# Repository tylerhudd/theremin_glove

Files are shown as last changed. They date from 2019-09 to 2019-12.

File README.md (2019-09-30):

# Theremin Glove
The Theremin Glove is a theremin inspired electronic instrument. Like the theremin, it is played with hand movements and gestures in the air. In electronics terms, it is a digitally controlled analog synthesizer and a wireless glove controller.
 
This project was started for the Johns Hopkins Whiting School of Engineering *Embedded Systems Lab* course in September 2019 and the working prototype should be demonstrated in December 2019. This course is an Electrical and Computer Engineerng graduate level capstone class that emulates the design process from requirement definitions to project demonstration.

I came up with the concept for this project as a way to combine areas of my engineering interests, which include:
* Analog circuit design
* Digital circuit design
* Firmware design (in this case, it's C programming for the ATMega328P)
* PCB design

## Features
* Pitch control - raising and lowering hand raises and lowers the frequency generated by the analog synthesizer
* Definable pitch range - the pitch range is set by first defining where the lowest note exists (i.e. place hand at the bottom of range) and press a button to start range recording. Then raise hand to where the highest note is and press a button to save. This is required because hand placement will be detected by an accelerometer which doesn't measure absolute height.
* Tone control - tilting hand in and out sweeps the resonant frequencies of the analog filters in the synthesizer
* Volume control - opening and closing hand raises and lowers the volume

## System
### Glove
* XBee3 wireless RF transceiver - transmits sensor data to digital analog synthesizer controller
* ATMega328P microcontroller - reads the sensor data and pushes to the XBee3 over SPI
* I2C interface to 6DoF sensor
* ADC interface to bend sensor
* USB-UART interface to ATMega328P and XBee3 for debug
* AVR SPI ISP header for ATMega328P programming
* Battery powered
* USB re-chargeable

### Digital Analog Synthesizer Controller
* XBee3 wireless RF transceiver - receives sensor data from glove
* ATMega328P microcontroller - interprets sensor data and calculates controls to analog synthesizer
* I2C interface to 4-channel DAC and IO expander
* USB-UART interface to ATMega328P and XBee3 for debug
* AVR SPI ISP header for ATMega328P programming

### Analog Synthesizer
* 4-channel DAC - provides control voltages to analog circuis
* I2C IO expander - provides a greater number of control signals
* VCO - generates square, triangle, and sine waveforms
* VCF - variable low pass, band pass, and high pass filters
* VCA - variable volume amplifier
* Analog muxes to select waveforms and filtering
* Audio output

### Power Board
* Input 12VAC (2A max)
* Ouput :
 * +3.3V DC (1.5A max) for digital circuits
 * +/-12V DC (1.5A max each) for analog circuits

### Block Diagram
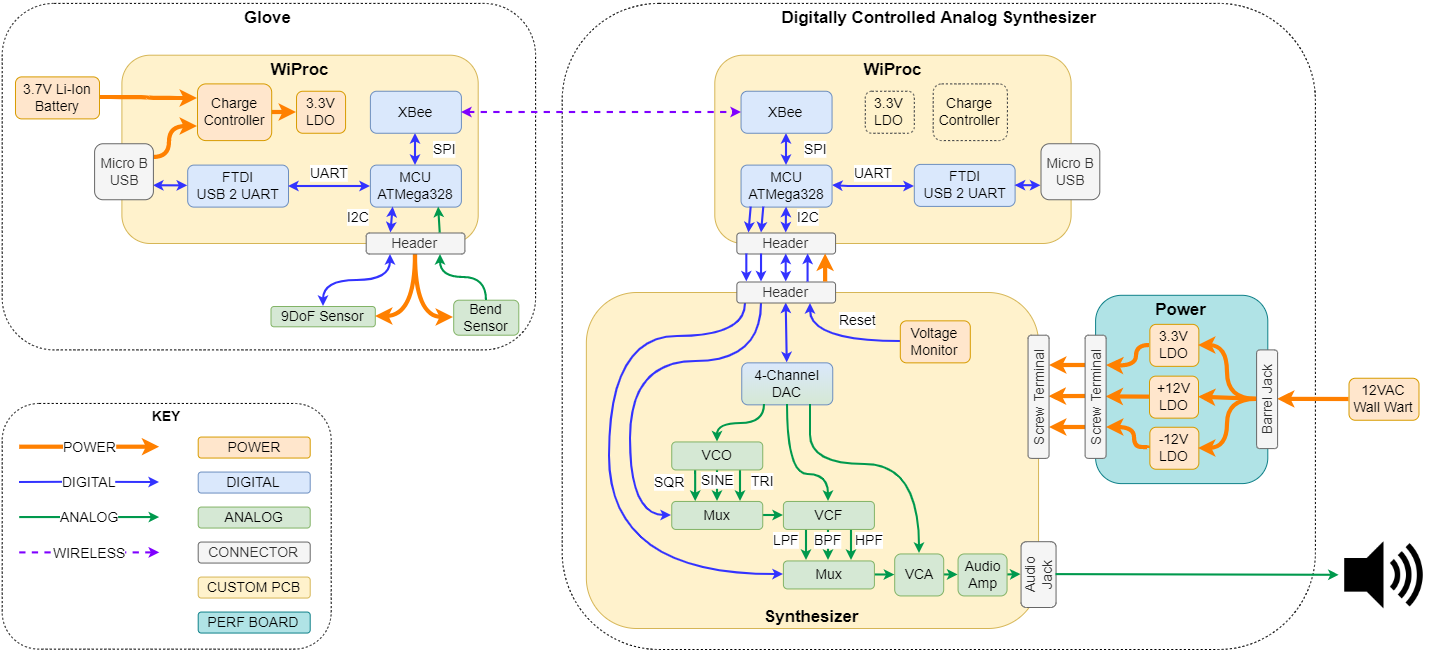
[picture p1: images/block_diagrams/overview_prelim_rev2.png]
block diagram


## Tools Used
* Atmel Studio - for ATMega328P C firmware development and programming
* KiCAD - for schematic capture and PCB design
* LTSpice - for analog and power simulations
* PuTTY - for serial console
* Github - for configuration management and project documentation

## Resources
* http://musicfromouterspace.com/
* https://oshpark.com/

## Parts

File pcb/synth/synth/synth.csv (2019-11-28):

Source: | C:\school\Johns_Hopkins\07_EmbeddedSystems\git\pcb\synth\synth\synth.sch
Date: | 11/10/2019 12:40:14 PM
Tool: | Eeschema (5.1.4)-1
Generator: | C:\Program Files\KiCad\bin\scripting\plugins/bom_csv_grouped_by_value.py
Component Count: | 161
Individual Components:
Item | Qty | Reference(s) | Value | LibPart | Footprint | Datasheet
 |  | BPF1 | TestPoint | Connector:TestPoint | TestPoint:TestPoint_Pad_1.0x1.0mm | ~
 |  | C1 | 680p | Device:C | Capacitor_SMD:C_0603_1608Metric_Pad1.05x0.95mm_HandSolder | ~
 |  | C2 | 680p | Device:C | Capacitor_SMD:C_0603_1608Metric_Pad1.05x0.95mm_HandSolder | ~
 |  | C3 | 680p | Device:C | Capacitor_SMD:C_0603_1608Metric_Pad1.05x0.95mm_HandSolder | ~
 |  | C4 | 1u | Device:C | Capacitor_SMD:C_0603_1608Metric_Pad1.05x0.95mm_HandSolder | ~
 |  | C5 | 1u | Device:C | Capacitor_SMD:C_0603_1608Metric_Pad1.05x0.95mm_HandSolder | ~
 |  | C6 | 0.47u | Device:C | Capacitor_SMD:C_0603_1608Metric_Pad1.05x0.95mm_HandSolder | ~
 |  | C7 | 0.1u | Device:C | Capacitor_SMD:C_0603_1608Metric_Pad1.05x0.95mm_HandSolder | ~
 |  | C8 | 0.1u | Device:C | Capacitor_SMD:C_0603_1608Metric_Pad1.05x0.95mm_HandSolder | ~
 |  | C9 | 0.1u | Device:C | Capacitor_SMD:C_0603_1608Metric_Pad1.05x0.95mm_HandSolder | ~
 |  | C10 | 0.1u | Device:C | Capacitor_SMD:C_0603_1608Metric_Pad1.05x0.95mm_HandSolder | ~
 |  | C11 | 0.1u | Device:C | Capacitor_SMD:C_0603_1608Metric_Pad1.05x0.95mm_HandSolder | ~
 |  | C12 | 1u | Device:C | Capacitor_SMD:C_0603_1608Metric_Pad1.05x0.95mm_HandSolder | ~
 |  | C13 | 0.1u | Device:C | Capacitor_SMD:C_0603_1608Metric_Pad1.05x0.95mm_HandSolder | ~
 |  | C14 | 0.1u | Device:C | Capacitor_SMD:C_0603_1608Metric_Pad1.05x0.95mm_HandSolder | ~
 |  | C15 | 0.1u | Device:C | Capacitor_SMD:C_0603_1608Metric_Pad1.05x0.95mm_HandSolder | ~
 |  | C16 | 0.1u | Device:C | Capacitor_SMD:C_0603_1608Metric_Pad1.05x0.95mm_HandSolder | ~
 |  | C17 | 0.1u | Device:C | Capacitor_SMD:C_0603_1608Metric_Pad1.05x0.95mm_HandSolder | ~
 |  | C18 | 1u | Device:C | Capacitor_SMD:C_0603_1608Metric_Pad1.05x0.95mm_HandSolder | ~
 |  | C19 | 0.1u | Device:C | Capacitor_SMD:C_0603_1608Metric_Pad1.05x0.95mm_HandSolder | ~
 |  | C20 | 0.1u | Device:C | Capacitor_SMD:C_0603_1608Metric_Pad1.05x0.95mm_HandSolder | ~
 |  | C21 | 0.1u | Device:C | Capacitor_SMD:C_0603_1608Metric_Pad1.05x0.95mm_HandSolder | ~
 |  | C22 | 0.1u | Device:C | Capacitor_SMD:C_0603_1608Metric_Pad1.05x0.95mm_HandSolder | ~
 |  | C23 | 1uF | Device:C | Capacitor_SMD:C_0603_1608Metric_Pad1.05x0.95mm_HandSolder | ~
 |  | C24 | 1uF | Device:C | Capacitor_SMD:C_0603_1608Metric_Pad1.05x0.95mm_HandSolder | ~
 |  | C25 | 0.1u | Device:C | Capacitor_SMD:C_0603_1608Metric_Pad1.05x0.95mm_HandSolder | ~
 |  | C26 | 0.1u | Device:C | Capacitor_SMD:C_0603_1608Metric_Pad1.05x0.95mm_HandSolder | ~
 |  | C27 | 0.1u | Device:C | Capacitor_SMD:C_0603_1608Metric_Pad1.05x0.95mm_HandSolder | ~
 |  | C28 | 0.1u | Device:C | Capacitor_SMD:C_0603_1608Metric_Pad1.05x0.95mm_HandSolder | ~
 |  | C29 | 2200p | Device:C | Capacitor_SMD:C_0603_1608Metric_Pad1.05x0.95mm_HandSolder | ~
 |  | C30 | 2200p | Device:C | Capacitor_SMD:C_0603_1608Metric_Pad1.05x0.95mm_HandSolder | ~
 |  | C31 | 68p | Device:C | Capacitor_SMD:C_0603_1608Metric_Pad1.05x0.95mm_HandSolder | ~
 |  | C32 | 0.1u | Device:C | Capacitor_SMD:C_0603_1608Metric_Pad1.05x0.95mm_HandSolder | ~
 |  | C33 | 0.1u | Device:C | Capacitor_SMD:C_0603_1608Metric_Pad1.05x0.95mm_HandSolder | ~
 |  | C34 | 1u | Device:C | Capacitor_SMD:C_0603_1608Metric_Pad1.05x0.95mm_HandSolder | ~
 |  | C35 | 0.1u | Device:C | Capacitor_SMD:C_0603_1608Metric_Pad1.05x0.95mm_HandSolder | ~
 |  | C36 | 0.1u | Device:C | Capacitor_SMD:C_0603_1608Metric_Pad1.05x0.95mm_HandSolder | ~
 |  | C37 | 1u | Device:C | Capacitor_SMD:C_0603_1608Metric_Pad1.05x0.95mm_HandSolder | ~
 |  | C38 | 0.1u | Device:C | Capacitor_SMD:C_0603_1608Metric_Pad1.05x0.95mm_HandSolder | ~
 |  | C39 | 0.1u | Device:C | Capacitor_SMD:C_0603_1608Metric_Pad1.05x0.95mm_HandSolder | ~
 |  | C40 | 0.1u | Device:C | Capacitor_SMD:C_0603_1608Metric_Pad1.05x0.95mm_HandSolder | ~
 |  | C41 | 0.1u | Device:C | Capacitor_SMD:C_0603_1608Metric_Pad1.05x0.95mm_HandSolder | ~
 |  | C42 | 0.1u | Device:C | Capacitor_SMD:C_0603_1608Metric_Pad1.05x0.95mm_HandSolder | ~
 |  | C43 | 0.1u | Device:C | Capacitor_SMD:C_0603_1608Metric_Pad1.05x0.95mm_HandSolder | ~
 |  | C44 | 0.1u | Device:C | Capacitor_SMD:C_0603_1608Metric_Pad1.05x0.95mm_HandSolder | ~
 |  | C45 | 1u | Device:C | Capacitor_SMD:C_0603_1608Metric_Pad1.05x0.95mm_HandSolder | ~
 |  | C46 | 0.1u | Device:C | Capacitor_SMD:C_0603_1608Metric_Pad1.05x0.95mm_HandSolder | ~
 |  | C47 | 10u | Device:C | Capacitor_SMD:C_0603_1608Metric_Pad1.05x0.95mm_HandSolder | ~
 |  | C48 | 0.1u | Device:C | Capacitor_SMD:C_0603_1608Metric_Pad1.05x0.95mm_HandSolder | ~
 |  | C49 | 0.1u | Device:C | Capacitor_SMD:C_0603_1608Metric_Pad1.05x0.95mm_HandSolder | ~
 |  | C51 | 10u | Device:C | Capacitor_SMD:C_0603_1608Metric_Pad1.05x0.95mm_HandSolder | ~
 |  | C52 | 10u | Device:C | Capacitor_SMD:C_0603_1608Metric_Pad1.05x0.95mm_HandSolder | ~
 |  | C53 | 10u | Device:C | Capacitor_SMD:C_0603_1608Metric_Pad1.05x0.95mm_HandSolder | ~
 |  | HPF1 | TestPoint | Connector:TestPoint | TestPoint:TestPoint_Pad_1.0x1.0mm | ~
 |  | J1 | Screw_Terminal_01x06 | Connector:Screw_Terminal_01x06 | TerminalBlock:TerminalBlock_bornier-6_P5.08mm | ~
 |  | J2 | AudioJack2 | Connector:AudioJack2 | Connector_PinHeader_2.54mm:PinHeader_1x02_P2.54mm_Vertical | ~
 |  | J3 | Conn_02x07_Odd_Even | Connector_Generic:Conn_02x07_Odd_Even | Connector_PinHeader_2.54mm:PinHeader_2x07_P2.54mm_Vertical | ~
 |  | J4 | Conn_01x02 | Connector_Generic:Conn_01x02 | Connector_PinHeader_2.54mm:PinHeader_1x02_P2.54mm_Vertical | ~
 |  | J5 | Conn_01x02 | Connector_Generic:Conn_01x02 | Connector_PinHeader_2.54mm:PinHeader_1x02_P2.54mm_Vertical | ~
 |  | LPF1 | TestPoint | Connector:TestPoint | TestPoint:TestPoint_Pad_1.0x1.0mm | ~
 |  | R1 | 10k | Device:R_US | Resistor_SMD:R_0603_1608Metric_Pad1.05x0.95mm_HandSolder | ~
 |  | R2 | 100k | Device:R_US | Resistor_SMD:R_0603_1608Metric_Pad1.05x0.95mm_HandSolder | ~
 |  | R3 | 100k | Device:R_US | Resistor_SMD:R_0603_1608Metric_Pad1.05x0.95mm_HandSolder | ~
 |  | R4 | 100k | Device:R_US | Resistor_SMD:R_0603_1608Metric_Pad1.05x0.95mm_HandSolder | ~
 |  | R5 | 100k | Device:R_US | Resistor_SMD:R_0603_1608Metric_Pad1.05x0.95mm_HandSolder | ~
 |  | R6 | 100k | Device:R_US | Resistor_SMD:R_0603_1608Metric_Pad1.05x0.95mm_HandSolder | ~
 |  | R7 | 680 | Device:R_US | Resistor_SMD:R_0603_1608Metric_Pad1.05x0.95mm_HandSolder | ~
 |  | R8 | 680 | Device:R_US | Resistor_SMD:R_0603_1608Metric_Pad1.05x0.95mm_HandSolder | ~
 |  | R9 | 20k | Device:R_US | Resistor_SMD:R_0603_1608Metric_Pad1.05x0.95mm_HandSolder | ~
 |  | R10 | 22 | Device:R_US | Resistor_SMD:R_0603_1608Metric_Pad1.05x0.95mm_HandSolder | ~
 |  | R11 | 100 | Device:R_US | Resistor_SMD:R_0603_1608Metric_Pad1.05x0.95mm_HandSolder | ~
 |  | R12 | 20k | Device:R_US | Resistor_SMD:R_0603_1608Metric_Pad1.05x0.95mm_HandSolder | ~
 |  | R13 | 10k | Device:R_US | Resistor_SMD:R_0603_1608Metric_Pad1.05x0.95mm_HandSolder | ~
 |  | R14 | 100 | Device:R_US | Resistor_SMD:R_0603_1608Metric_Pad1.05x0.95mm_HandSolder | ~
 |  | R15 | 100 | Device:R_US | Resistor_SMD:R_0603_1608Metric_Pad1.05x0.95mm_HandSolder | ~
 |  | R16 | 10k | Device:R_US | Resistor_SMD:R_0603_1608Metric_Pad1.05x0.95mm_HandSolder | ~
 |  | R17 | 100 | Device:R_US | Resistor_SMD:R_0603_1608Metric_Pad1.05x0.95mm_HandSolder | ~
 |  | R18 | 100 | Device:R_US | Resistor_SMD:R_0603_1608Metric_Pad1.05x0.95mm_HandSolder | ~
 |  | R19 | 10k | Device:R_US | Resistor_SMD:R_0603_1608Metric_Pad1.05x0.95mm_HandSolder | ~
 |  | R20 | 10k | Device:R_US | Resistor_SMD:R_0603_1608Metric_Pad1.05x0.95mm_HandSolder | ~
 |  | R21 | 10k | Device:R_US | Resistor_SMD:R_0603_1608Metric_Pad1.05x0.95mm_HandSolder | ~
 |  | R22 | 10k | Device:R_US | Resistor_SMD:R_0603_1608Metric_Pad1.05x0.95mm_HandSolder | ~
 |  | R23 | 10k | Device:R_US | Resistor_SMD:R_0603_1608Metric_Pad1.05x0.95mm_HandSolder | ~
 |  | R24 | 10k | Device:R_US | Resistor_SMD:R_0603_1608Metric_Pad1.05x0.95mm_HandSolder | ~
 |  | R25 | 10k | Device:R_US | Resistor_SMD:R_0603_1608Metric_Pad1.05x0.95mm_HandSolder | ~
 |  | R26 | 20k | Device:R_US | Resistor_SMD:R_0603_1608Metric_Pad1.05x0.95mm_HandSolder | ~
 |  | R27 | 5.1k | Device:R_US | Resistor_SMD:R_0603_1608Metric_Pad1.05x0.95mm_HandSolder | ~
 |  | R28 | 68k | Device:R_US | Resistor_SMD:R_0603_1608Metric_Pad1.05x0.95mm_HandSolder | ~
 |  | R29 | 100k | Device:R_US | Resistor_SMD:R_0603_1608Metric_Pad1.05x0.95mm_HandSolder | ~
 |  | R30 | 50 | Device:R_US | Resistor_SMD:R_0603_1608Metric_Pad1.05x0.95mm_HandSolder | ~
 |  | R31 | 50 | Device:R_US | Resistor_SMD:R_0603_1608Metric_Pad1.05x0.95mm_HandSolder | ~
 |  | R32 | 1k | Device:R_US | Resistor_SMD:R_0603_1608Metric_Pad1.05x0.95mm_HandSolder | ~
 |  | R33 | 10k | Device:R_US | Resistor_SMD:R_0603_1608Metric_Pad1.05x0.95mm_HandSolder | ~
 |  | R34 | 51k | Device:R_US | Resistor_SMD:R_0603_1608Metric_Pad1.05x0.95mm_HandSolder | ~
 |  | R35 | 1k | Device:R_US | Resistor_SMD:R_0603_1608Metric_Pad1.05x0.95mm_HandSolder | ~
 |  | R36 | 1k | Device:R_US | Resistor_SMD:R_0603_1608Metric_Pad1.05x0.95mm_HandSolder | ~
 |  | R37 | 20k | Device:R_US | Resistor_SMD:R_0603_1608Metric_Pad1.05x0.95mm_HandSolder | ~
 |  | R38 | 20k | Device:R_US | Resistor_SMD:R_0603_1608Metric_Pad1.05x0.95mm_HandSolder | ~
 |  | R39 | 1k | Device:R_US | Resistor_SMD:R_0603_1608Metric_Pad1.05x0.95mm_HandSolder | ~
 |  | R40 | 1k | Device:R_US | Resistor_SMD:R_0603_1608Metric_Pad1.05x0.95mm_HandSolder | ~
 |  | R41 | 5.1k | Device:R_US | Resistor_SMD:R_0603_1608Metric_Pad1.05x0.95mm_HandSolder | ~
 |  | R42 | 470k | Device:R_US | Resistor_SMD:R_0603_1608Metric_Pad1.05x0.95mm_HandSolder | ~
 |  | R43 | 1k | Device:R_US | Resistor_SMD:R_0603_1608Metric_Pad1.05x0.95mm_HandSolder | ~
 |  | R44 | 1k | Device:R_US | Resistor_SMD:R_0603_1608Metric_Pad1.05x0.95mm_HandSolder | ~
 |  | R45 | 100k | Device:R_US | Resistor_SMD:R_0603_1608Metric_Pad1.05x0.95mm_HandSolder | ~
 |  | R46 | 10k | Device:R_US | Resistor_SMD:R_0603_1608Metric_Pad1.05x0.95mm_HandSolder | ~
 |  | R47 | 10k | Device:R_US | Resistor_SMD:R_0603_1608Metric_Pad1.05x0.95mm_HandSolder | ~
 |  | R48 | 510 | Device:R_US | Resistor_SMD:R_0603_1608Metric_Pad1.05x0.95mm_HandSolder | ~
 |  | R49 | 510 | Device:R_US | Resistor_SMD:R_0603_1608Metric_Pad1.05x0.95mm_HandSolder | ~
 |  | R50 | 51k | Device:R_US | Resistor_SMD:R_0603_1608Metric_Pad1.05x0.95mm_HandSolder | ~
 |  | R51 | 5.1k | Device:R_US | Resistor_SMD:R_0603_1608Metric_Pad1.05x0.95mm_HandSolder | ~
 |  | R52 | 20k | Device:R_US | Resistor_SMD:R_0603_1608Metric_Pad1.05x0.95mm_HandSolder | ~
 |  | R53 | 10k | Device:R_US | Resistor_SMD:R_0603_1608Metric_Pad1.05x0.95mm_HandSolder | ~
 |  | R54 | 10k | Device:R_US | Resistor_SMD:R_0603_1608Metric_Pad1.05x0.95mm_HandSolder | ~
 |  | R55 | 10k | Device:R_US | Resistor_SMD:R_0603_1608Metric_Pad1.05x0.95mm_HandSolder | ~
 |  | R56 | 10k | Device:R_US | Resistor_SMD:R_0603_1608Metric_Pad1.05x0.95mm_HandSolder | ~
 |  | R57 | 10k | Device:R_US | Resistor_SMD:R_0603_1608Metric_Pad1.05x0.95mm_HandSolder | ~
 |  | R58 | 1.2k | Device:R_US | Resistor_SMD:R_0603_1608Metric_Pad1.05x0.95mm_HandSolder | ~
 |  | R59 | 10k | Device:R_US | Resistor_SMD:R_0603_1608Metric_Pad1.05x0.95mm_HandSolder | ~
 |  | R60 | 10k | Device:R_US | Resistor_SMD:R_0603_1608Metric_Pad1.05x0.95mm_HandSolder | ~
 |  | R61 | 91k | Device:R_US | Resistor_SMD:R_0603_1608Metric_Pad1.05x0.95mm_HandSolder | ~
 |  | R62 | 10k | Device:R_US | Resistor_SMD:R_0603_1608Metric_Pad1.05x0.95mm_HandSolder | ~
 |  | R63 | 10k | Device:R_US | Resistor_SMD:R_0603_1608Metric_Pad1.05x0.95mm_HandSolder | ~
 |  | R64 | 10k | Device:R_US | Resistor_SMD:R_0603_1608Metric_Pad1.05x0.95mm_HandSolder | ~
 |  | R65 | 10k | Device:R_US | Resistor_SMD:R_0603_1608Metric_Pad1.05x0.95mm_HandSolder | ~
 |  | R66 | 1.2k | Device:R_US | Resistor_SMD:R_0603_1608Metric_Pad1.05x0.95mm_HandSolder | ~
 |  | R67 | 10k | Device:R_US | Resistor_SMD:R_0603_1608Metric_Pad1.05x0.95mm_HandSolder | ~
 |  | R68 | 10k | Device:R_US | Resistor_SMD:R_0603_1608Metric_Pad1.05x0.95mm_HandSolder | ~
 |  | R69 | 91k | Device:R_US | Resistor_SMD:R_0603_1608Metric_Pad1.05x0.95mm_HandSolder | ~
 |  | R70 | 10k | Device:R_US | Resistor_SMD:R_0603_1608Metric_Pad1.05x0.95mm_HandSolder | ~
 |  | R71 | 10k | Device:R_US | Resistor_SMD:R_0603_1608Metric_Pad1.05x0.95mm_HandSolder | ~
 |  | R72 | 10k | Device:R_US | Resistor_SMD:R_0603_1608Metric_Pad1.05x0.95mm_HandSolder | ~
 |  | R73 | 10k | Device:R_US | Resistor_SMD:R_0603_1608Metric_Pad1.05x0.95mm_HandSolder | ~
 |  | R74 | 1.2k | Device:R_US | Resistor_SMD:R_0603_1608Metric_Pad1.05x0.95mm_HandSolder | ~
 |  | R75 | 10k | Device:R_US | Resistor_SMD:R_0603_1608Metric_Pad1.05x0.95mm_HandSolder | ~
 |  | R76 | 10k | Device:R_US | Resistor_SMD:R_0603_1608Metric_Pad1.05x0.95mm_HandSolder | ~
 |  | R77 | 91k | Device:R_US | Resistor_SMD:R_0603_1608Metric_Pad1.05x0.95mm_HandSolder | ~
 |  | R78 | 10k | Device:R_US | Resistor_SMD:R_0603_1608Metric_Pad1.05x0.95mm_HandSolder | ~
 |  | R79 | 10k | Device:R_US | Resistor_SMD:R_0603_1608Metric_Pad1.05x0.95mm_HandSolder | ~
 |  | R80 | 10k | Device:R_US | Resistor_SMD:R_0603_1608Metric_Pad1.05x0.95mm_HandSolder | ~
 |  | R81 | 1.2k | Device:R_US | Resistor_SMD:R_0603_1608Metric_Pad1.05x0.95mm_HandSolder | ~
 |  | R82 | 1.2k | Device:R_US | Resistor_SMD:R_0603_1608Metric_Pad1.05x0.95mm_HandSolder | ~
 |  | SIN1 | TestPoint | Connector:TestPoint | TestPoint:TestPoint_Pad_1.0x1.0mm | ~
 |  | SQR1 | TestPoint | Connector:TestPoint | TestPoint:TestPoint_Pad_1.0x1.0mm | ~
 |  | TRI1 | TestPoint | Connector:TestPoint | TestPoint:TestPoint_Pad_1.0x1.0mm | ~
 |  | U1 | LM13700 | Amplifier_Operational:LM13700 | Package_SO:SOIC-16_3.9x9.9mm_P1.27mm | http://www.ti.com/lit/ds/symlink/lm13700.pdf
 |  | U2 | LM13700 | Amplifier_Operational:LM13700 | Package_SO:SOIC-16_3.9x9.9mm_P1.27mm | http://www.ti.com/lit/ds/symlink/lm13700.pdf
 |  | U3 | LM13700 | Amplifier_Operational:LM13700 | Package_SO:SOIC-16_3.9x9.9mm_P1.27mm | http://www.ti.com/lit/ds/symlink/lm13700.pdf
 |  | U4 | LM13700 | Amplifier_Operational:LM13700 | Package_SO:SOIC-16_3.9x9.9mm_P1.27mm | http://www.ti.com/lit/ds/symlink/lm13700.pdf
 |  | U5 | LM13700 | Amplifier_Operational:LM13700 | Package_SO:SOIC-16_3.9x9.9mm_P1.27mm | http://www.ti.com/lit/ds/symlink/lm13700.pdf
 |  | U6 | OPA172IDBVR | opa172idbvr:OPA172IDBVR | Package_TO_SOT_SMD:SOT-23-5 | http://ww1.microchip.com/downloads/en/DeviceDoc/22141b.pdf
 |  | U7 | OPA172IDBVR | opa172idbvr:OPA172IDBVR | Package_TO_SOT_SMD:SOT-23-5 | http://ww1.microchip.com/downloads/en/DeviceDoc/22141b.pdf
 |  | U8 | OPA172IDBVR | opa172idbvr:OPA172IDBVR | Package_TO_SOT_SMD:SOT-23-5 | http://ww1.microchip.com/downloads/en/DeviceDoc/22141b.pdf
 |  | U9 | MUX508 | mux508:MUX508 | Package_SO:SOIC-16_3.9x9.9mm_P1.27mm | http://www.ti.com/lit/gpn/sn74cbt3253
 |  | U10 | OPA172IDBVR | opa172idbvr:OPA172IDBVR | Package_TO_SOT_SMD:SOT-23-5 | http://ww1.microchip.com/downloads/en/DeviceDoc/22141b.pdf
 |  | U11 | MUX508 | mux508:MUX508 | Package_SO:SOIC-16_3.9x9.9mm_P1.27mm | http://www.ti.com/lit/gpn/sn74cbt3253
 |  | U12 | PCF8574A | Interface_Expansion:PCF8574A | Package_SO:SOIC-16W_7.5x10.3mm_P1.27mm | http://www.nxp.com/documents/data_sheet/PCF8574_PCF8574A.pdf
 |  | U13 | AD5694R | ad5694r:AD5694R | Package_SO:TSSOP-16_4.4x5mm_P0.65mm | https://www.analog.com/media/en/technical-documentation/data-sheets/AD5697R.pdf
 |  | U14 | OPA4172 | Amplifier_Operational:OPA4340UA | Package_SO:SOIC-14_3.9x8.7mm_P1.27mm | http://www.ti.com/lit/ds/symlink/opa340.pdf
 |  | U15 | OPA4172 | Amplifier_Operational:OPA4340UA | Package_SO:SOIC-14_3.9x8.7mm_P1.27mm | http://www.ti.com/lit/ds/symlink/opa340.pdf
 |  | U16 | OPA4172 | Amplifier_Operational:OPA4340UA | Package_SO:SOIC-14_3.9x8.7mm_P1.27mm | http://www.ti.com/lit/ds/symlink/opa340.pdf
Collated Components:
Item | Qty | Reference(s) | Value | LibPart | Footprint | Datasheet
1 | 6 | BPF1, HPF1, LPF1, SIN1, SQR1, TRI1 | TestPoint | Connector:TestPoint | TestPoint:TestPoint_Pad_1.0x1.0mm | ~
2 | 3 | C1, C2, C3 | 680p | Device:C | Capacitor_SMD:C_0603_1608Metric_Pad1.05x0.95mm_HandSolder | ~
3 | 7 | C4, C5, C12, C18, C34, C37, C45 | 1u | Device:C | Capacitor_SMD:C_0603_1608Metric_Pad1.05x0.95mm_HandSolder | ~
4 | 1 | C6 | 0.47u | Device:C | Capacitor_SMD:C_0603_1608Metric_Pad1.05x0.95mm_HandSolder | ~
5 | 32 | C7, C8, C9, C10, C11, C13, C14, C15, C16, C17, C19, C20, C21, C22, C25, C26, C27, C28, C32, C33, C35, C36, C38, C39, C40, C41, C42, C43, C44, C46, C48, C49 | 0.1u | Device:C | Capacitor_SMD:C_0603_1608Metric_Pad1.05x0.95mm_HandSolder | ~
6 | 2 | C23, C24 | 1uF | Device:C | Capacitor_SMD:C_0603_1608Metric_Pad1.05x0.95mm_HandSolder | ~
7 | 2 | C29, C30 | 2200p | Device:C | Capacitor_SMD:C_0603_1608Metric_Pad1.05x0.95mm_HandSolder | ~
8 | 1 | C31 | 68p | Device:C | Capacitor_SMD:C_0603_1608Metric_Pad1.05x0.95mm_HandSolder | ~
9 | 4 | C47, C51, C52, C53 | 10u | Device:C | Capacitor_SMD:C_0603_1608Metric_Pad1.05x0.95mm_HandSolder | ~
10 | 1 | J1 | Screw_Terminal_01x06 | Connector:Screw_Terminal_01x06 | TerminalBlock:TerminalBlock_bornier-6_P5.08mm | ~
11 | 1 | J2 | AudioJack2 | Connector:AudioJack2 | Connector_PinHeader_2.54mm:PinHeader_1x02_P2.54mm_Vertical | ~
12 | 1 | J3 | Conn_02x07_Odd_Even | Connector_Generic:Conn_02x07_Odd_Even | Connector_PinHeader_2.54mm:PinHeader_2x07_P2.54mm_Vertical | ~
13 | 2 | J4, J5 | Conn_01x02 | Connector_Generic:Conn_01x02 | Connector_PinHeader_2.54mm:PinHeader_1x02_P2.54mm_Vertical | ~
14 | 35 | R1, R13, R16, R19, R20, R21, R22, R23, R24, R25, R33, R46, R47, R53, R54, R55, R56, R57, R59, R60, R62, R63, R64, R65, R67, R68, R70, R71, R72, R73, R75, R76, R78, R79, R80 | 10k | Device:R_US | Resistor_SMD:R_0603_1608Metric_Pad1.05x0.95mm_HandSolder | ~
15 | 7 | R2, R3, R4, R5, R6, R29, R45 | 100k | Device:R_US | Resistor_SMD:R_0603_1608Metric_Pad1.05x0.95mm_HandSolder | ~
16 | 2 | R7, R8 | 680 | Device:R_US | Resistor_SMD:R_0603_1608Metric_Pad1.05x0.95mm_HandSolder | ~
17 | 6 | R9, R12, R26, R37, R38, R52 | 20k | Device:R_US | Resistor_SMD:R_0603_1608Metric_Pad1.05x0.95mm_HandSolder | ~
18 | 1 | R10 | 22 | Device:R_US | Resistor_SMD:R_0603_1608Metric_Pad1.05x0.95mm_HandSolder | ~
19 | 5 | R11, R14, R15, R17, R18 | 100 | Device:R_US | Resistor_SMD:R_0603_1608Metric_Pad1.05x0.95mm_HandSolder | ~
20 | 3 | R27, R41, R51 | 5.1k | Device:R_US | Resistor_SMD:R_0603_1608Metric_Pad1.05x0.95mm_HandSolder | ~
21 | 1 | R28 | 68k | Device:R_US | Resistor_SMD:R_0603_1608Metric_Pad1.05x0.95mm_HandSolder | ~
22 | 2 | R30, R31 | 50 | Device:R_US | Resistor_SMD:R_0603_1608Metric_Pad1.05x0.95mm_HandSolder | ~
23 | 7 | R32, R35, R36, R39, R40, R43, R44 | 1k | Device:R_US | Resistor_SMD:R_0603_1608Metric_Pad1.05x0.95mm_HandSolder | ~
24 | 2 | R34, R50 | 51k | Device:R_US | Resistor_SMD:R_0603_1608Metric_Pad1.05x0.95mm_HandSolder | ~
25 | 1 | R42 | 470k | Device:R_US | Resistor_SMD:R_0603_1608Metric_Pad1.05x0.95mm_HandSolder | ~
26 | 2 | R48, R49 | 510 | Device:R_US | Resistor_SMD:R_0603_1608Metric_Pad1.05x0.95mm_HandSolder | ~
27 | 5 | R58, R66, R74, R81, R82 | 1.2k | Device:R_US | Resistor_SMD:R_0603_1608Metric_Pad1.05x0.95mm_HandSolder | ~
28 | 3 | R61, R69, R77 | 91k | Device:R_US | Resistor_SMD:R_0603_1608Metric_Pad1.05x0.95mm_HandSolder | ~
29 | 5 | U1, U2, U3, U4, U5 | LM13700 | Amplifier_Operational:LM13700 | Package_SO:SOIC-16_3.9x9.9mm_P1.27mm | http://www.ti.com/lit/ds/symlink/lm13700.pdf
30 | 4 | U6, U7, U8, U10 | OPA172IDBVR | opa172idbvr:OPA172IDBVR | Package_TO_SOT_SMD:SOT-23-5 | http://ww1.microchip.com/downloads/en/DeviceDoc/22141b.pdf
31 | 2 | U9, U11 | MUX508 | mux508:MUX508 | Package_SO:SOIC-16_3.9x9.9mm_P1.27mm | http://www.ti.com/lit/gpn/sn74cbt3253
32 | 1 | U12 | PCF8574A | Interface_Expansion:PCF8574A | Package_SO:SOIC-16W_7.5x10.3mm_P1.27mm | http://www.nxp.com/documents/data_sheet/PCF8574_PCF8574A.pdf
33 | 1 | U13 | AD5694R | ad5694r:AD5694R | Package_SO:TSSOP-16_4.4x5mm_P0.65mm | https://www.analog.com/media/en/technical-documentation/data-sheets/AD5697R.pdf
34 | 3 | U14, U15, U16 | OPA4172 | Amplifier_Operational:OPA4340UA | Package_SO:SOIC-14_3.9x8.7mm_P1.27mm | http://www.ti.com/lit/ds/symlink/opa340.pdf

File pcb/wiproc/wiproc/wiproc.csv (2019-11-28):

Source: | C:\school\Johns_Hopkins\07_EmbeddedSystems\git\pcb\wiproc\wiproc\wiproc.sch
Date: | 11/10/2019 12:41:09 PM
Tool: | Eeschema (5.1.4)-1
Generator: | C:\Program Files\KiCad\bin\scripting\plugins/bom_csv_grouped_by_value.py
Component Count: | 71
Individual Components:
Item | Qty | Reference(s) | Value | LibPart | Footprint | Datasheet | PN
 |  | C1 | 0.1uF | Device:C | Capacitor_SMD:C_0603_1608Metric_Pad1.05x0.95mm_HandSolder | ~
 |  | C2 | 0.1uF | Device:C | Capacitor_SMD:C_0603_1608Metric_Pad1.05x0.95mm_HandSolder | ~
 |  | C3 | 0.1uF | Device:C | Capacitor_SMD:C_0603_1608Metric_Pad1.05x0.95mm_HandSolder | ~
 |  | C4 | 0.1uF | Device:C | Capacitor_SMD:C_0603_1608Metric_Pad1.05x0.95mm_HandSolder | ~
 |  | C5 | 0.1uF | Device:C | Capacitor_SMD:C_0603_1608Metric_Pad1.05x0.95mm_HandSolder | ~
 |  | C6 | 18pF | Device:C | Capacitor_SMD:C_0603_1608Metric_Pad1.05x0.95mm_HandSolder | ~
 |  | C7 | 18pF | Device:C | Capacitor_SMD:C_0603_1608Metric_Pad1.05x0.95mm_HandSolder | ~
 |  | C8 | 0.1uF | Device:C | Capacitor_SMD:C_0603_1608Metric_Pad1.05x0.95mm_HandSolder | ~
 |  | C9 | 4.7uF | Device:C | Capacitor_SMD:C_0603_1608Metric_Pad1.05x0.95mm_HandSolder | ~
 |  | C10 | 0.1uF | Device:C | Capacitor_SMD:C_0603_1608Metric_Pad1.05x0.95mm_HandSolder | ~
 |  | C11 | 0.01uF | Device:C | Capacitor_SMD:C_0603_1608Metric_Pad1.05x0.95mm_HandSolder | ~
 |  | C12 | 47pF | Device:C | Capacitor_SMD:C_0603_1608Metric_Pad1.05x0.95mm_HandSolder | ~
 |  | C13 | 47pF | Device:C | Capacitor_SMD:C_0603_1608Metric_Pad1.05x0.95mm_HandSolder | ~
 |  | C14 | 0.1uF | Device:C | Capacitor_SMD:C_0603_1608Metric_Pad1.05x0.95mm_HandSolder | ~
 |  | C15 | 1uF | Device:C | Capacitor_SMD:C_0603_1608Metric_Pad1.05x0.95mm_HandSolder | ~
 |  | C16 | 4.7uF | Device:C | Capacitor_SMD:C_0603_1608Metric_Pad1.05x0.95mm_HandSolder | ~
 |  | C17 | 4.7uF | Device:C | Capacitor_SMD:C_0603_1608Metric_Pad1.05x0.95mm_HandSolder | ~
 |  | C18 | 0.1uF | Device:C | Capacitor_SMD:C_0603_1608Metric_Pad1.05x0.95mm_HandSolder | ~
 |  | C19 | 47pF | Device:C | Capacitor_SMD:C_0603_1608Metric_Pad1.05x0.95mm_HandSolder | ~
 |  | C20 | 47pF | Device:C | Capacitor_SMD:C_0603_1608Metric_Pad1.05x0.95mm_HandSolder | ~
 |  | C21 | 0.1uF | Device:C | Capacitor_SMD:C_0603_1608Metric_Pad1.05x0.95mm_HandSolder | ~
 |  | C22 | 47pF | Device:C | Capacitor_SMD:C_0603_1608Metric_Pad1.05x0.95mm_HandSolder | ~
 |  | C23 | 47pF | Device:C | Capacitor_SMD:C_0603_1608Metric_Pad1.05x0.95mm_HandSolder | ~
 |  | D1 | LED | Device:LED | LED_SMD:LED_0805_2012Metric_Pad1.15x1.40mm_HandSolder | ~
 |  | D2 | LED | Device:LED | LED_SMD:LED_0805_2012Metric_Pad1.15x1.40mm_HandSolder | ~
 |  | D3 | 1N4148WS | Device:D | Diode_SMD:D_SOD-323_HandSoldering | ~
 |  | D4 | LED | Device:LED | LED_SMD:LED_0805_2012Metric_Pad1.15x1.40mm_HandSolder | ~
 |  | D5 | LED | Device:LED | LED_SMD:LED_0805_2012Metric_Pad1.15x1.40mm_HandSolder | ~
 |  | D6 | LED | Device:LED | LED_SMD:LED_0805_2012Metric_Pad1.15x1.40mm_HandSolder | ~
 |  | J1 | Conn_01x10_Female | Connector:Conn_01x10_Female | Connector_PinSocket_2.00mm:PinSocket_1x10_P2.00mm_Vertical | ~
 |  | J2 | Conn_01x10_Female_xbee | conn_01x10_female_xbee:Conn_01x10_Female_xbee | Connector_PinSocket_2.00mm:PinSocket_1x10_P2.00mm_Vertical | ~
 |  | J3 | Conn_02x07_Odd_Even | Connector_Generic:Conn_02x07_Odd_Even | Connector_PinHeader_2.54mm:PinHeader_2x07_P2.54mm_Vertical | ~
 |  | J4 | Conn_02x03_Odd_Even | Connector_Generic:Conn_02x03_Odd_Even | Connector_PinHeader_2.54mm:PinHeader_2x03_P2.54mm_Vertical_SMD | ~
 |  | J5 | Conn_01x02_Male | Connector:Conn_01x02_Male | Connector_PinHeader_2.54mm:PinHeader_1x02_P2.54mm_Vertical | ~
 |  | J6 | USB_B_Micro | Connector:USB_B_Micro | Connector_USB:USB_Micro-B_Molex_47346-0001 | ~
 |  | J7 | Conn_01x02 | Connector_Generic:Conn_01x02 | Connector_JST:JST_PH_S2B-PH-SM4-TB_1x02-1MP_P2.00mm_Horizontal | ~
 |  | R1 | 10k | Device:R_US | Resistor_SMD:R_0603_1608Metric_Pad1.05x0.95mm_HandSolder | ~
 |  | R2 | 10k | Device:R_US | Resistor_SMD:R_0603_1608Metric_Pad1.05x0.95mm_HandSolder | ~
 |  | R3 | 10k | Device:R_US | Resistor_SMD:R_0603_1608Metric_Pad1.05x0.95mm_HandSolder | ~
 |  | R4 | 10k | Device:R_US | Resistor_SMD:R_0603_1608Metric_Pad1.05x0.95mm_HandSolder | ~
 |  | R5 | 10k | Device:R_US | Resistor_SMD:R_0603_1608Metric_Pad1.05x0.95mm_HandSolder | ~
 |  | R6 | 10k | Device:R_US | Resistor_SMD:R_0603_1608Metric_Pad1.05x0.95mm_HandSolder | ~
 |  | R7 | 10k | Device:R_US | Resistor_SMD:R_0603_1608Metric_Pad1.05x0.95mm_HandSolder | ~
 |  | R8 | 220 | Device:R_US | Resistor_SMD:R_0603_1608Metric_Pad1.05x0.95mm_HandSolder | ~
 |  | R9 | 220 | Device:R_US | Resistor_SMD:R_0603_1608Metric_Pad1.05x0.95mm_HandSolder | ~
 |  | R10 | 220 | Device:R_US | Resistor_SMD:R_0603_1608Metric_Pad1.05x0.95mm_HandSolder | ~
 |  | R11 | 10k | Device:R_US | Resistor_SMD:R_0603_1608Metric_Pad1.05x0.95mm_HandSolder | ~
 |  | R12 | 10k | Device:R_US | Resistor_SMD:R_0603_1608Metric_Pad1.05x0.95mm_HandSolder | ~
 |  | R13 | 27 | Device:R_US | Resistor_SMD:R_0603_1608Metric_Pad1.05x0.95mm_HandSolder | ~
 |  | R14 | 27 | Device:R_US | Resistor_SMD:R_0603_1608Metric_Pad1.05x0.95mm_HandSolder | ~
 |  | R15 | 220 | Device:R_US | Resistor_SMD:R_0603_1608Metric_Pad1.05x0.95mm_HandSolder | ~
 |  | R16 | 220 | Device:R_US | Resistor_SMD:R_0603_1608Metric_Pad1.05x0.95mm_HandSolder | ~
 |  | R17 | 470 | Device:R_US | Resistor_SMD:R_0603_1608Metric_Pad1.05x0.95mm_HandSolder | ~
 |  | R18 | 10k | Device:R_US | Resistor_SMD:R_0603_1608Metric_Pad1.05x0.95mm_HandSolder | ~
 |  | R19 | 0 | Device:R_US | Resistor_SMD:R_0603_1608Metric_Pad1.05x0.95mm_HandSolder | ~
 |  | R20 | 100k | Device:R_US | Resistor_SMD:R_0603_1608Metric_Pad1.05x0.95mm_HandSolder | ~
 |  | R21 | 10k | Device:R_US | Resistor_SMD:R_0603_1608Metric_Pad1.05x0.95mm_HandSolder | ~
 |  | R22 | 10k | Device:R_US | Resistor_SMD:R_0603_1608Metric_Pad1.05x0.95mm_HandSolder | ~
 |  | SW1 | SW_Push | Switch:SW_Push | Button_Switch_SMD:SW_SPST_TL3342 | ~
 |  | SW2 | SW_Push | Switch:SW_Push | Button_Switch_SMD:SW_SPST_TL3342 | ~
 |  | SW3 | SW_Push | Switch:SW_Push | Button_Switch_SMD:SW_SPST_TL3342 | ~
 |  | SW4 | SW_Push | Switch:SW_Push | Button_Switch_SMD:SW_SPST_TL3342 | ~
 |  | U1 | ATmega328P-AU | atmega48p:ATmega328P-AU | Package_QFP:TQFP-32_7x7mm_P0.8mm | http://ww1.microchip.com/downloads/en/DeviceDoc/ATmega328_P%20AVR%20MCU%20with%20picoPower%20Technology%20Data%20Sheet%2040001984A.pdf
 |  | U2 | FODM8071 | wiproc-rescue:FODM8071-fodm8071 | Package_SO:SO-5_4.4x3.6mm_P1.27mm | https://www.vishay.com/docs/83725/4n25.pdf
 |  | U3 | 74LVC1G97 | 74xGxx:74LVC1G97 | Package_TO_SOT_SMD:SOT-23-6 | http://www.ti.com/lit/sg/scyt129e/scyt129e.pdf
 |  | U4 | FT231XS | ft231xs_3v3in:FT231XS | Package_SO:SSOP-20_3.9x8.7mm_P0.635mm | http://www.ftdichip.com/Products/ICs/FT231X.html
 |  | U5 | TLV70033_SOT23-5 | Regulator_Linear:TLV70033_SOT23-5 | Package_TO_SOT_SMD:SOT-23-5 | http://www.ti.com/lit/ds/symlink/tlv700.pdf
 |  | U6 | MCP73831-2-OT | Battery_Management:MCP73831-2-OT | Package_TO_SOT_SMD:SOT-23-5 | http://ww1.microchip.com/downloads/en/DeviceDoc/20001984g.pdf
 |  | U7 | TLV118 | tlv118:TLV118 | Package_TO_SOT_SMD:SOT-23-6 | http://www.ti.com/lit/ds/symlink/opa355.pdf
 |  | U8 | TLV118 | tlv118:TLV118 | Package_TO_SOT_SMD:SOT-23-6 | http://www.ti.com/lit/ds/symlink/opa355.pdf
 |  | Y1 | 16MHz | Device:Crystal | Crystal:Crystal_SMD_ECS_CSM3X-2Pin_7.6x4.1mm | ~ | ABLS7M
Collated Components:
Item | Qty | Reference(s) | Value | LibPart | Footprint | Datasheet | PN
1 | 10 | C1, C2, C3, C4, C5, C8, C10, C14, C18, C21 | 0.1uF | Device:C | Capacitor_SMD:C_0603_1608Metric_Pad1.05x0.95mm_HandSolder | ~
2 | 2 | C6, C7 | 18pF | Device:C | Capacitor_SMD:C_0603_1608Metric_Pad1.05x0.95mm_HandSolder | ~
3 | 3 | C9, C16, C17 | 4.7uF | Device:C | Capacitor_SMD:C_0603_1608Metric_Pad1.05x0.95mm_HandSolder | ~
4 | 1 | C11 | 0.01uF | Device:C | Capacitor_SMD:C_0603_1608Metric_Pad1.05x0.95mm_HandSolder | ~
5 | 6 | C12, C13, C19, C20, C22, C23 | 47pF | Device:C | Capacitor_SMD:C_0603_1608Metric_Pad1.05x0.95mm_HandSolder | ~
6 | 1 | C15 | 1uF | Device:C | Capacitor_SMD:C_0603_1608Metric_Pad1.05x0.95mm_HandSolder | ~
7 | 5 | D1, D2, D4, D5, D6 | LED | Device:LED | LED_SMD:LED_0805_2012Metric_Pad1.15x1.40mm_HandSolder | ~
8 | 1 | D3 | 1N4148WS | Device:D | Diode_SMD:D_SOD-323_HandSoldering | ~
9 | 1 | J1 | Conn_01x10_Female | Connector:Conn_01x10_Female | Connector_PinSocket_2.00mm:PinSocket_1x10_P2.00mm_Vertical | ~
10 | 1 | J2 | Conn_01x10_Female_xbee | conn_01x10_female_xbee:Conn_01x10_Female_xbee | Connector_PinSocket_2.00mm:PinSocket_1x10_P2.00mm_Vertical | ~
11 | 1 | J3 | Conn_02x07_Odd_Even | Connector_Generic:Conn_02x07_Odd_Even | Connector_PinHeader_2.54mm:PinHeader_2x07_P2.54mm_Vertical | ~
12 | 1 | J4 | Conn_02x03_Odd_Even | Connector_Generic:Conn_02x03_Odd_Even | Connector_PinHeader_2.54mm:PinHeader_2x03_P2.54mm_Vertical_SMD | ~
13 | 1 | J5 | Conn_01x02_Male | Connector:Conn_01x02_Male | Connector_PinHeader_2.54mm:PinHeader_1x02_P2.54mm_Vertical | ~
14 | 1 | J6 | USB_B_Micro | Connector:USB_B_Micro | Connector_USB:USB_Micro-B_Molex_47346-0001 | ~
15 | 1 | J7 | Conn_01x02 | Connector_Generic:Conn_01x02 | Connector_JST:JST_PH_S2B-PH-SM4-TB_1x02-1MP_P2.00mm_Horizontal | ~
16 | 12 | R1, R2, R3, R4, R5, R6, R7, R11, R12, R18, R21, R22 | 10k | Device:R_US | Resistor_SMD:R_0603_1608Metric_Pad1.05x0.95mm_HandSolder | ~
17 | 5 | R8, R9, R10, R15, R16 | 220 | Device:R_US | Resistor_SMD:R_0603_1608Metric_Pad1.05x0.95mm_HandSolder | ~
18 | 2 | R13, R14 | 27 | Device:R_US | Resistor_SMD:R_0603_1608Metric_Pad1.05x0.95mm_HandSolder | ~
19 | 1 | R17 | 470 | Device:R_US | Resistor_SMD:R_0603_1608Metric_Pad1.05x0.95mm_HandSolder | ~
20 | 1 | R19 | 0 | Device:R_US | Resistor_SMD:R_0603_1608Metric_Pad1.05x0.95mm_HandSolder | ~
21 | 1 | R20 | 100k | Device:R_US | Resistor_SMD:R_0603_1608Metric_Pad1.05x0.95mm_HandSolder | ~
22 | 4 | SW1, SW2, SW3, SW4 | SW_Push | Switch:SW_Push | Button_Switch_SMD:SW_SPST_TL3342 | ~
23 | 1 | U1 | ATmega328P-AU | atmega48p:ATmega328P-AU | Package_QFP:TQFP-32_7x7mm_P0.8mm | http://ww1.microchip.com/downloads/en/DeviceDoc/ATmega328_P%20AVR%20MCU%20with%20picoPower%20Technology%20Data%20Sheet%2040001984A.pdf
24 | 1 | U2 | FODM8071 | wiproc-rescue:FODM8071-fodm8071 | Package_SO:SO-5_4.4x3.6mm_P1.27mm | https://www.vishay.com/docs/83725/4n25.pdf
25 | 1 | U3 | 74LVC1G97 | 74xGxx:74LVC1G97 | Package_TO_SOT_SMD:SOT-23-6 | http://www.ti.com/lit/sg/scyt129e/scyt129e.pdf
26 | 1 | U4 | FT231XS | ft231xs_3v3in:FT231XS | Package_SO:SSOP-20_3.9x8.7mm_P0.635mm | http://www.ftdichip.com/Products/ICs/FT231X.html
27 | 1 | U5 | TLV70033_SOT23-5 | Regulator_Linear:TLV70033_SOT23-5 | Package_TO_SOT_SMD:SOT-23-5 | http://www.ti.com/lit/ds/symlink/tlv700.pdf
28 | 1 | U6 | MCP73831-2-OT | Battery_Management:MCP73831-2-OT | Package_TO_SOT_SMD:SOT-23-5 | http://ww1.microchip.com/downloads/en/DeviceDoc/20001984g.pdf
29 | 2 | U7, U8 | TLV118 | tlv118:TLV118 | Package_TO_SOT_SMD:SOT-23-6 | http://www.ti.com/lit/ds/symlink/opa355.pdf
30 | 1 | Y1 | 16MHz | Device:Crystal | Crystal:Crystal_SMD_ECS_CSM3X-2Pin_7.6x4.1mm | ~ | ABLS7M

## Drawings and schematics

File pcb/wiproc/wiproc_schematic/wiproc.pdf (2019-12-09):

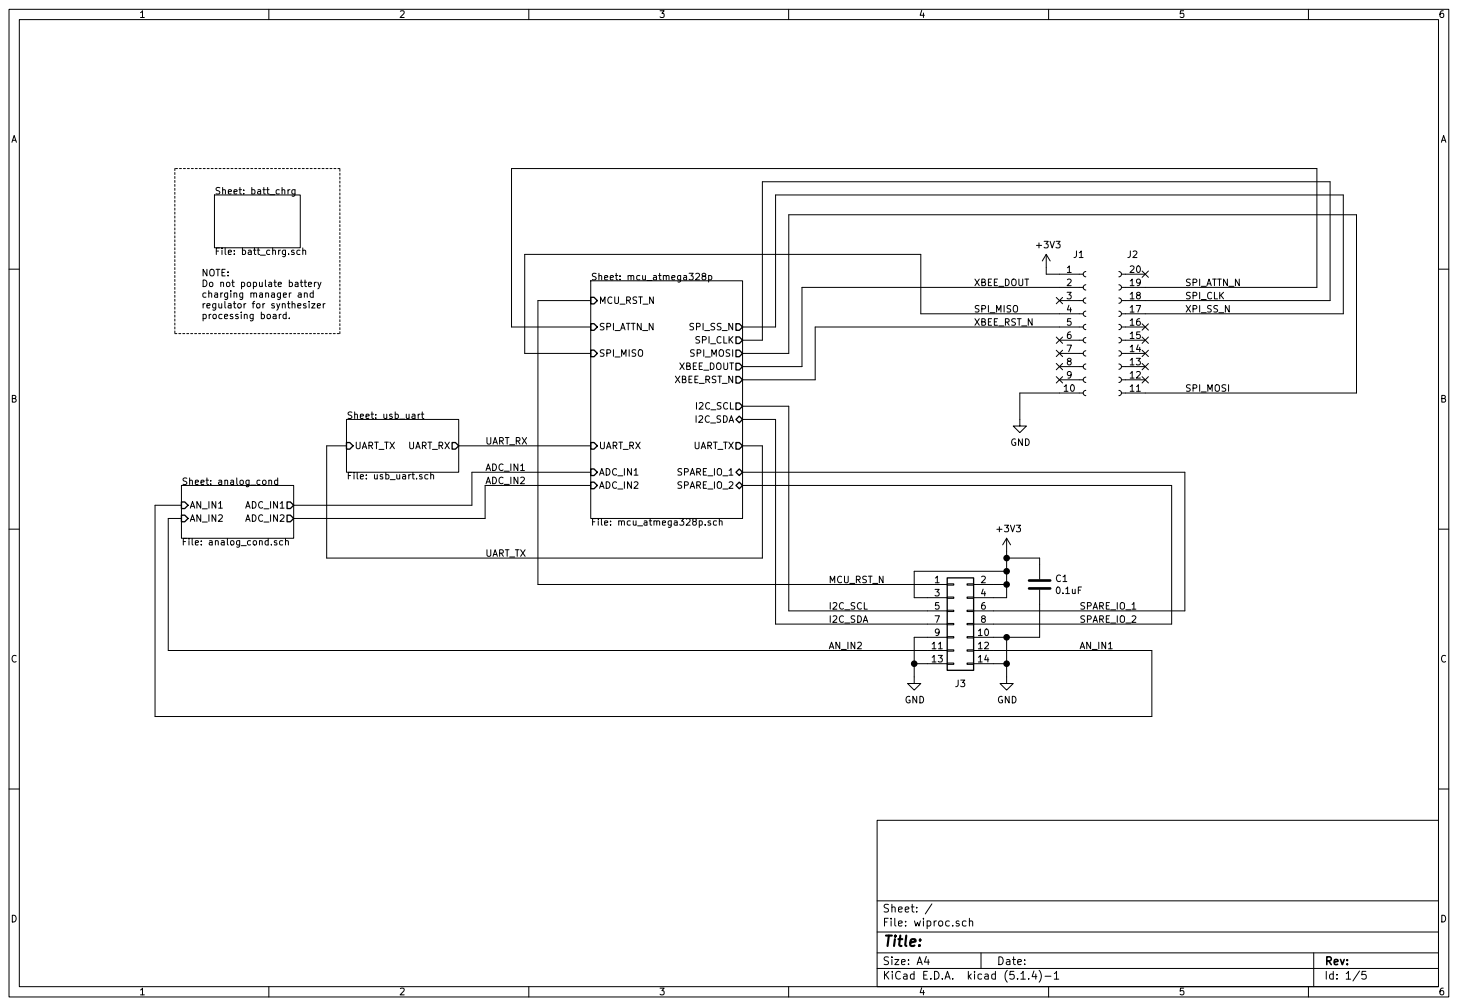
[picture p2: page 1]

SPARE_IO_1 SPARE_IO_2 NOTE: Do not populate battery

11 | 12
13 | 14

File: wiproc.sch Sheet: /
Id: 1/5 Title:

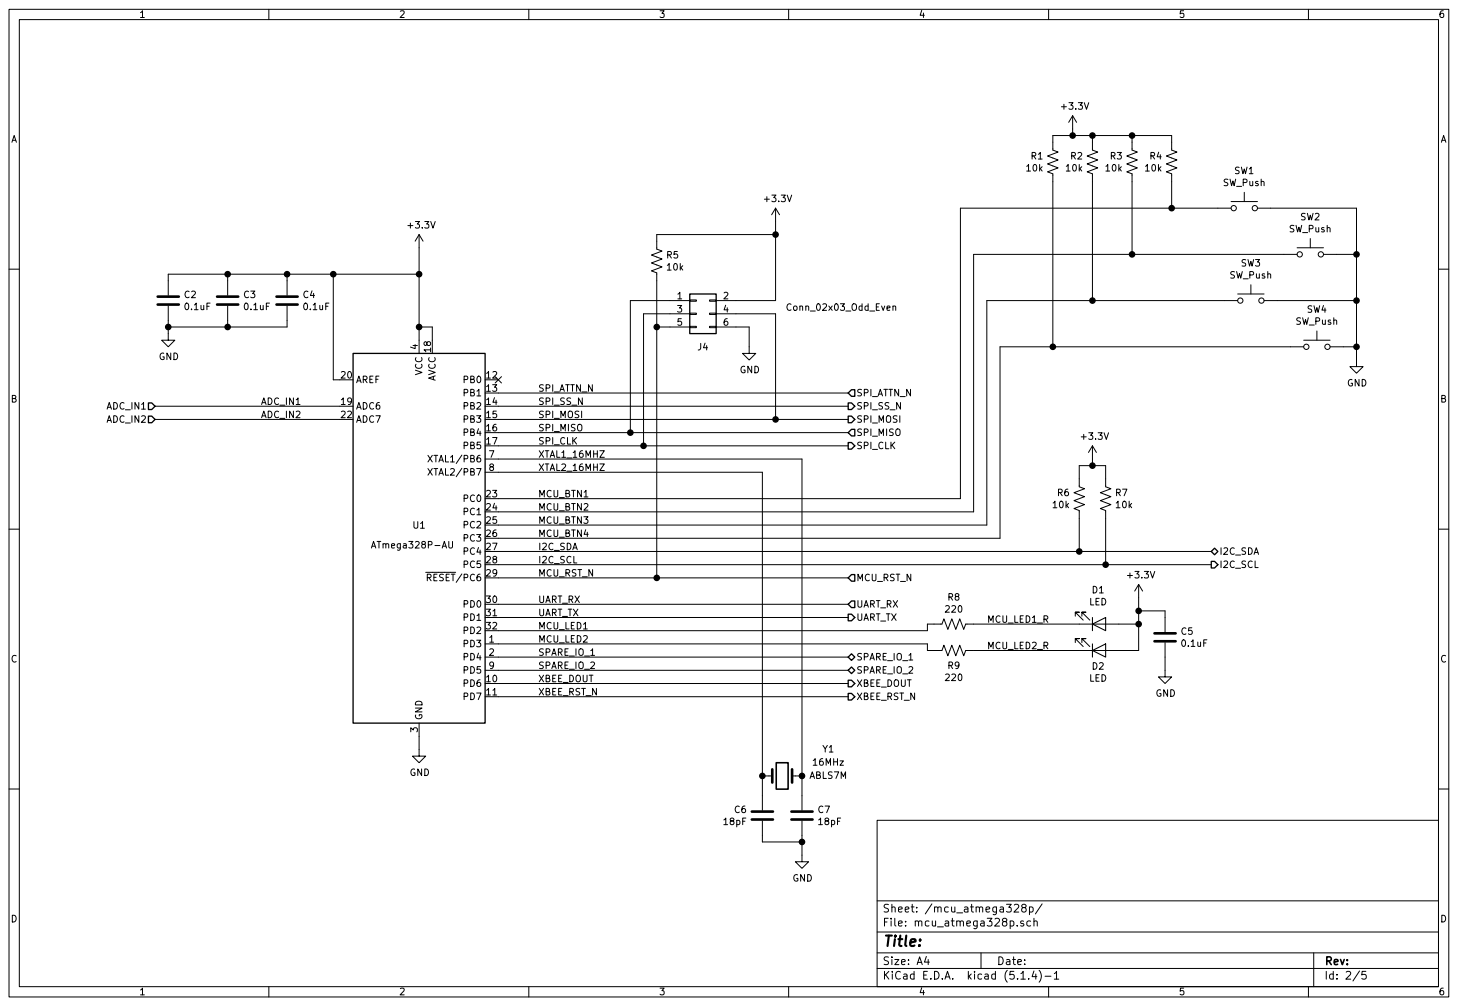
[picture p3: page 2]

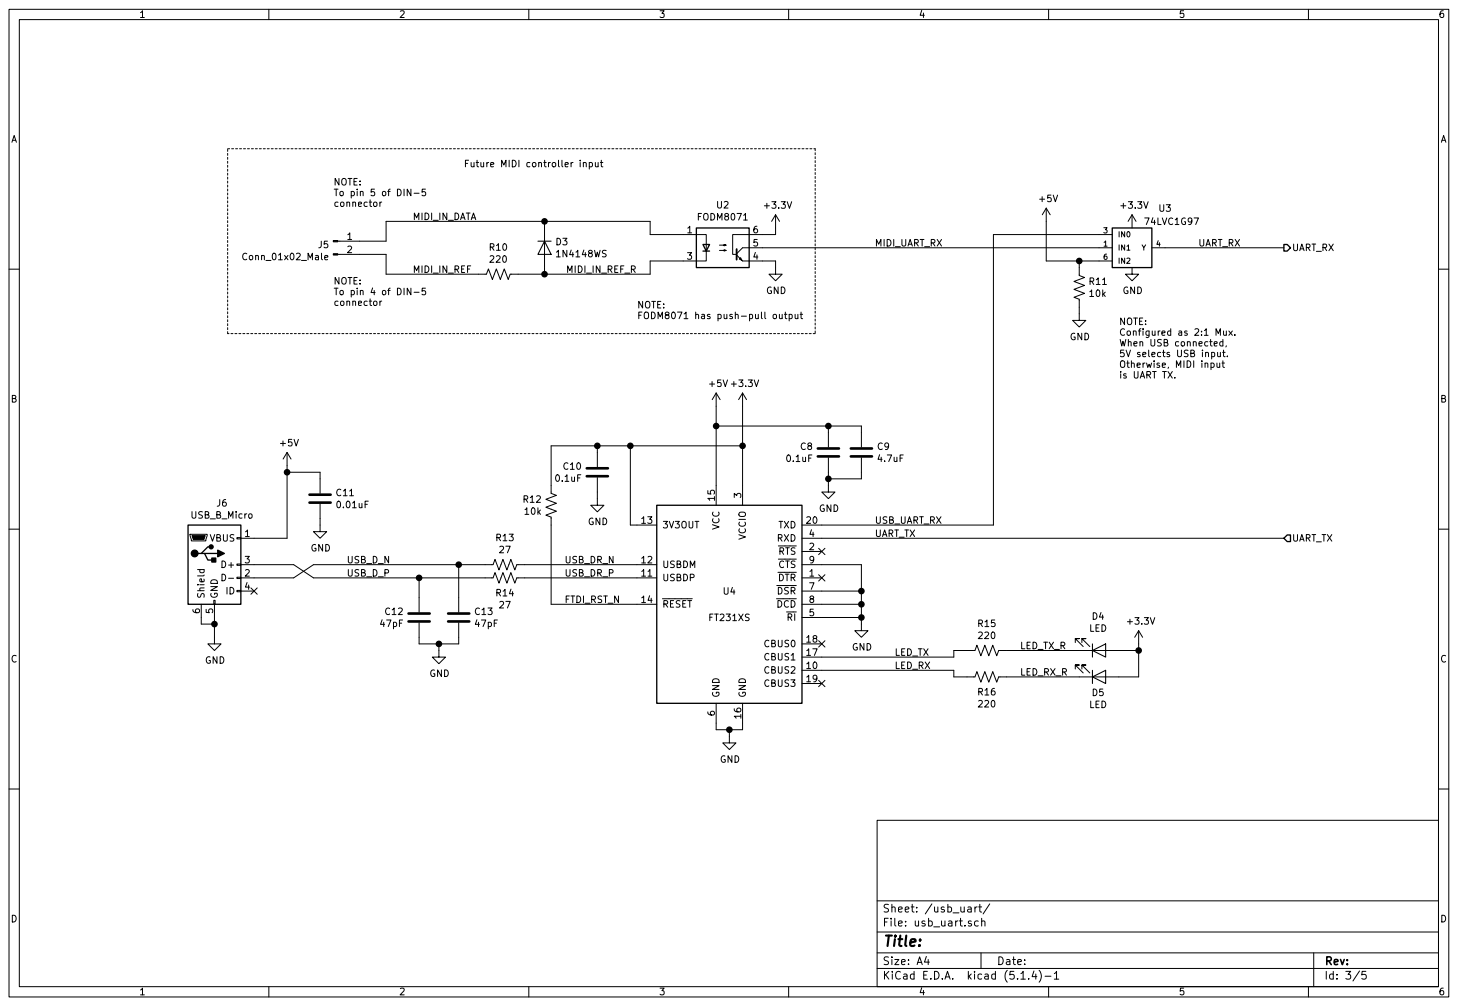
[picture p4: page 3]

is UART TX. Future MIDI controller input NOTE: To pin 4 of DIN-5
connector NOTE: To pin 5 of DIN-5

UART_RX NOTE: Configured as 2:1 Mux. When USB connected, 5V selects USB input.

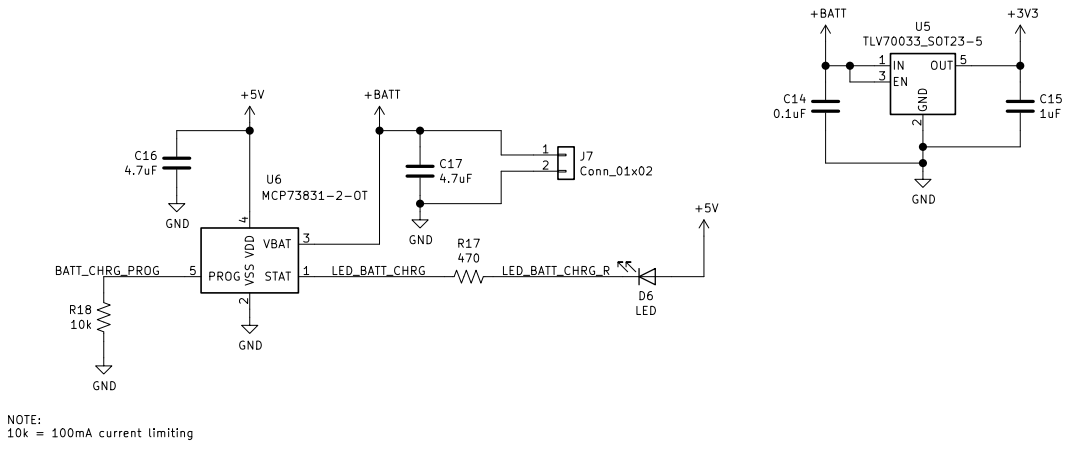
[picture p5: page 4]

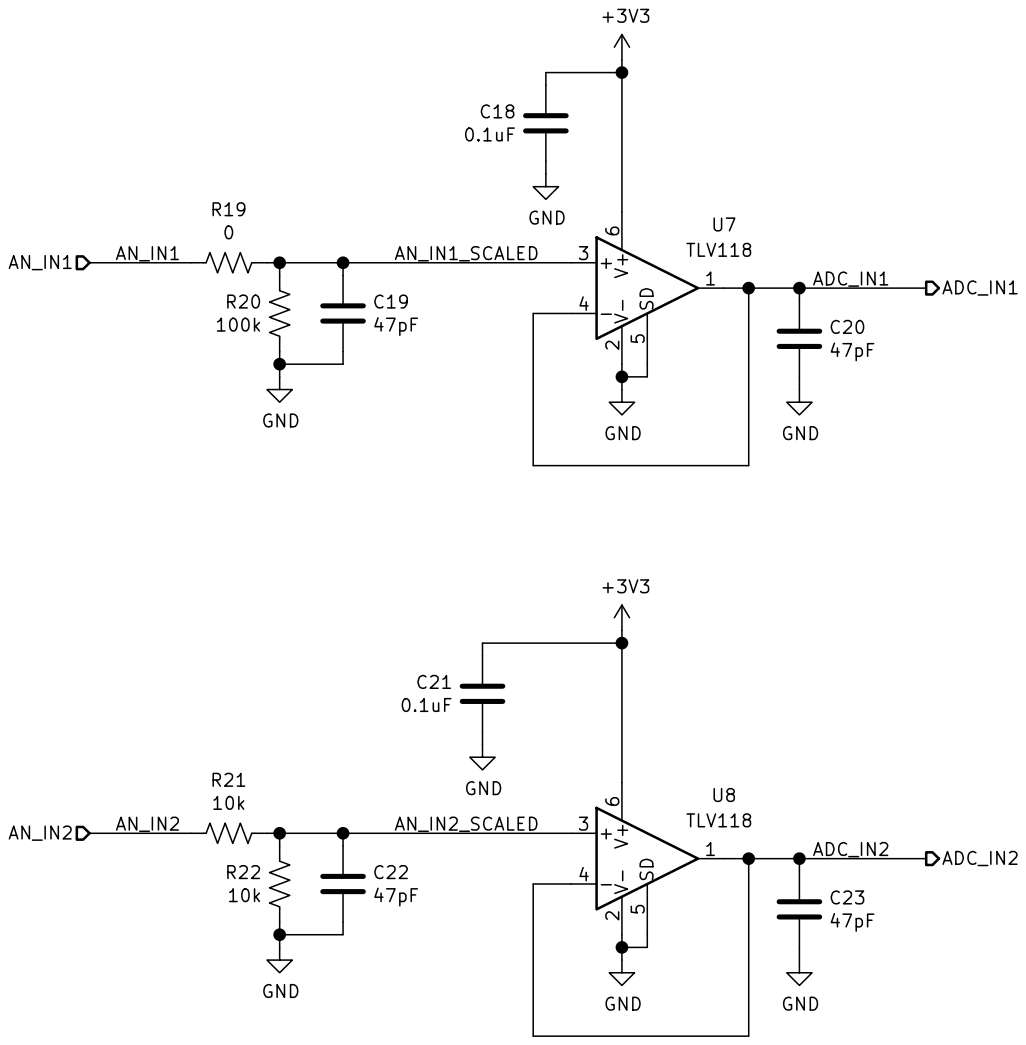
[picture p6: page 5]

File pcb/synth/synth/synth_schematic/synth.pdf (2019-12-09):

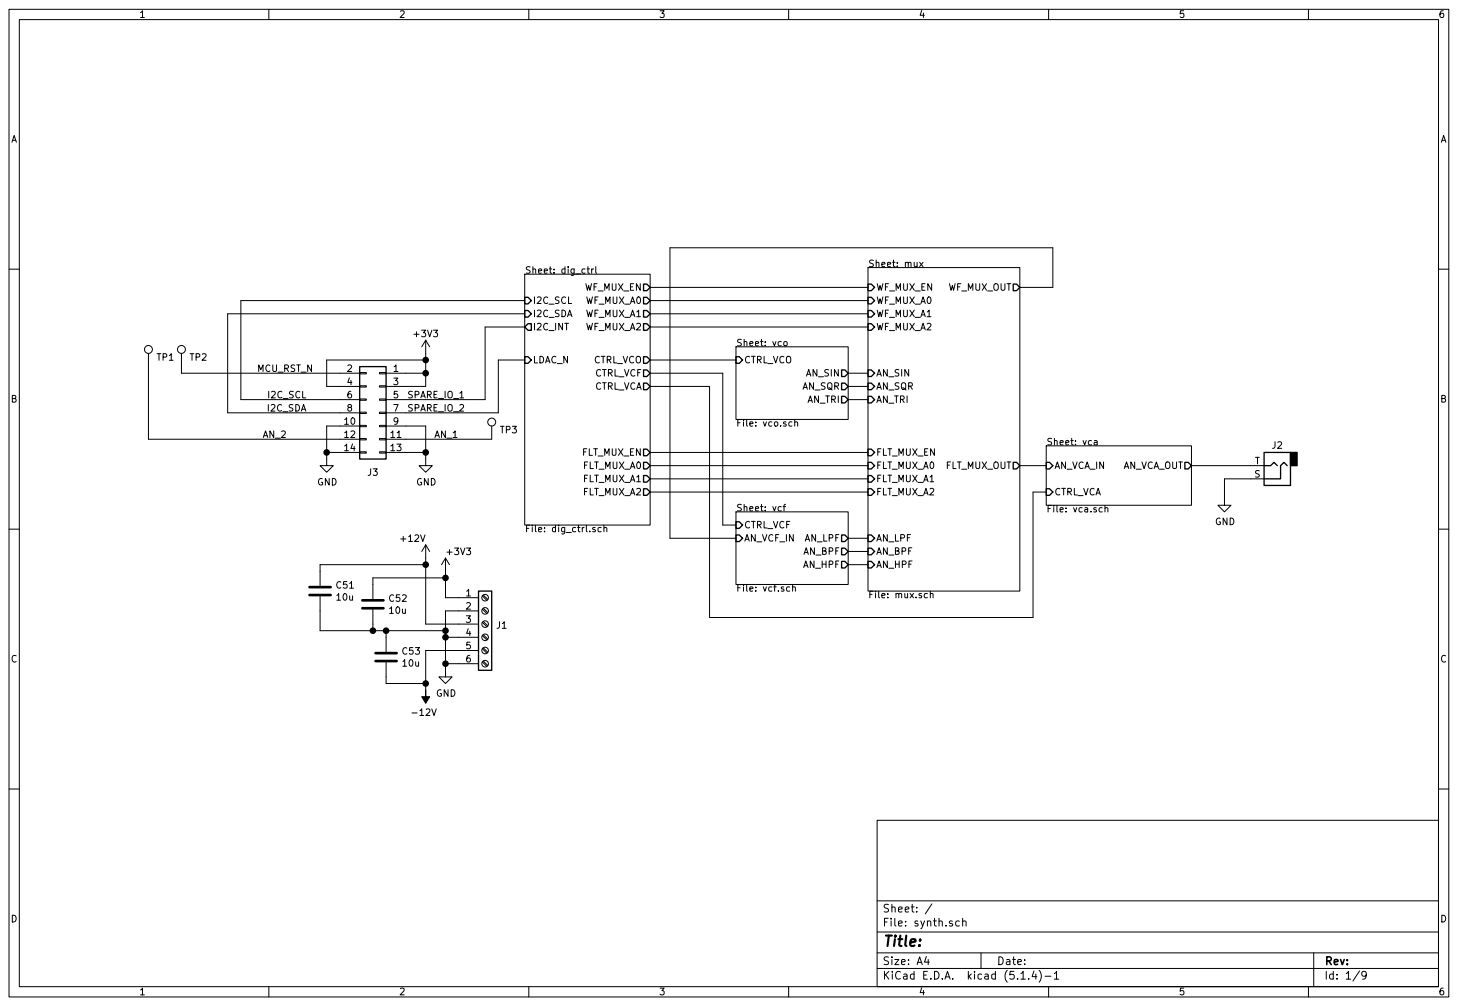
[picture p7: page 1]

Sheet: vco File: vco.sch CTRL_VCO

12 | 11
14 | 13

FLT_MUX_OUT Sheet: vcf File: vcf.sch AN_VCF_IN

File: synth.sch Sheet: /
Id: 1/9 Title:

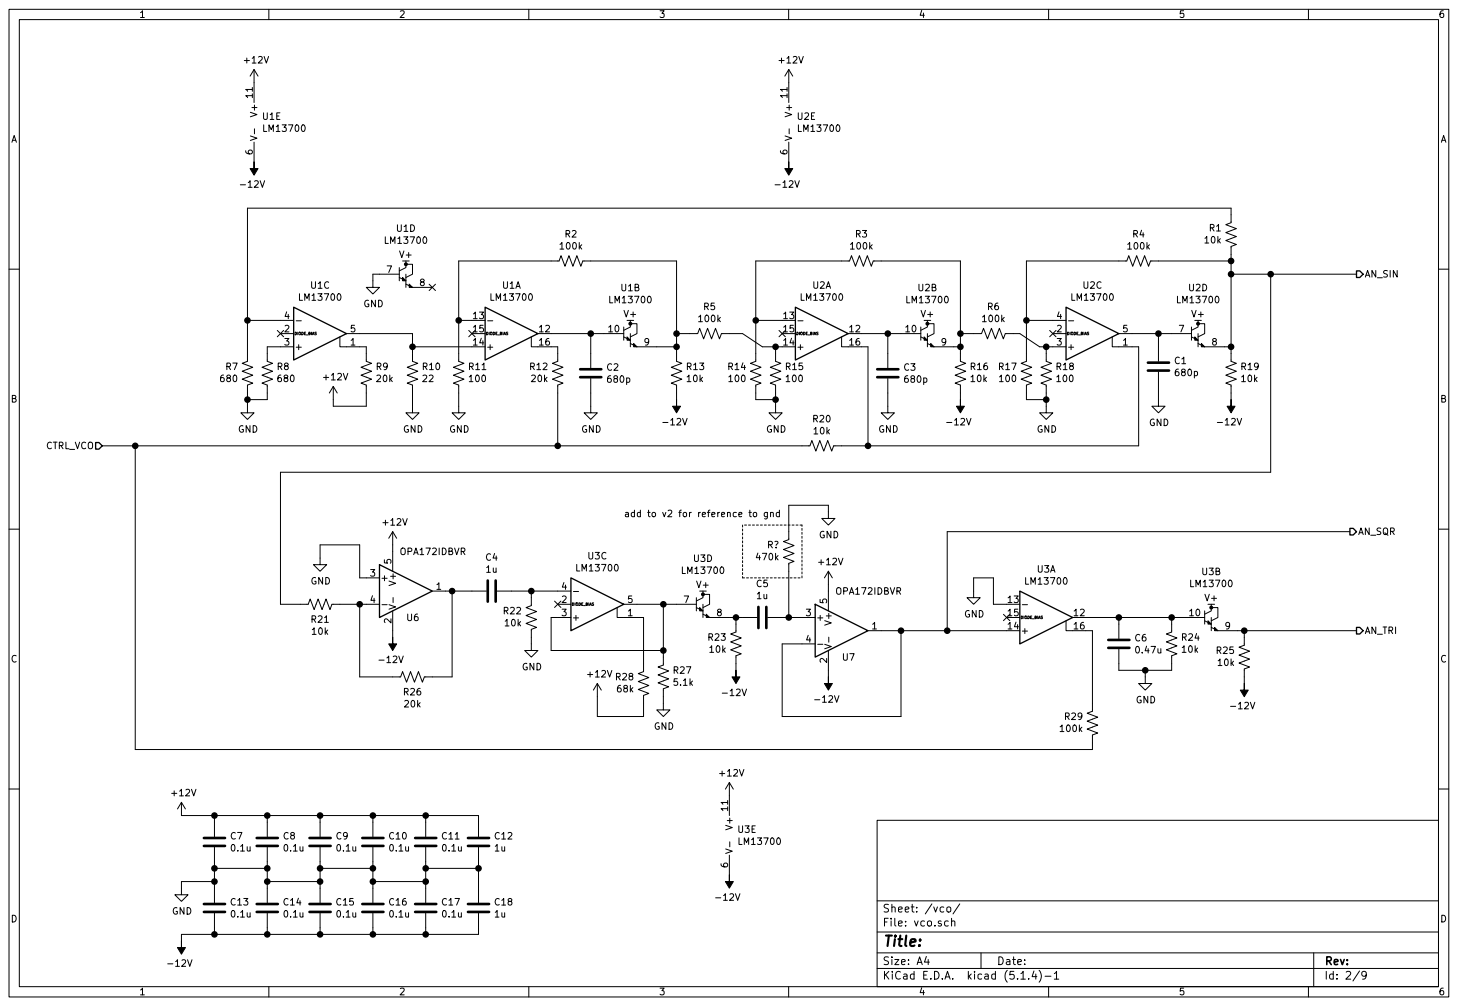
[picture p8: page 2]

add to v2 for reference to gnd

Id: 2/9 Title: File: vco.sch Sheet: /vco/ GND

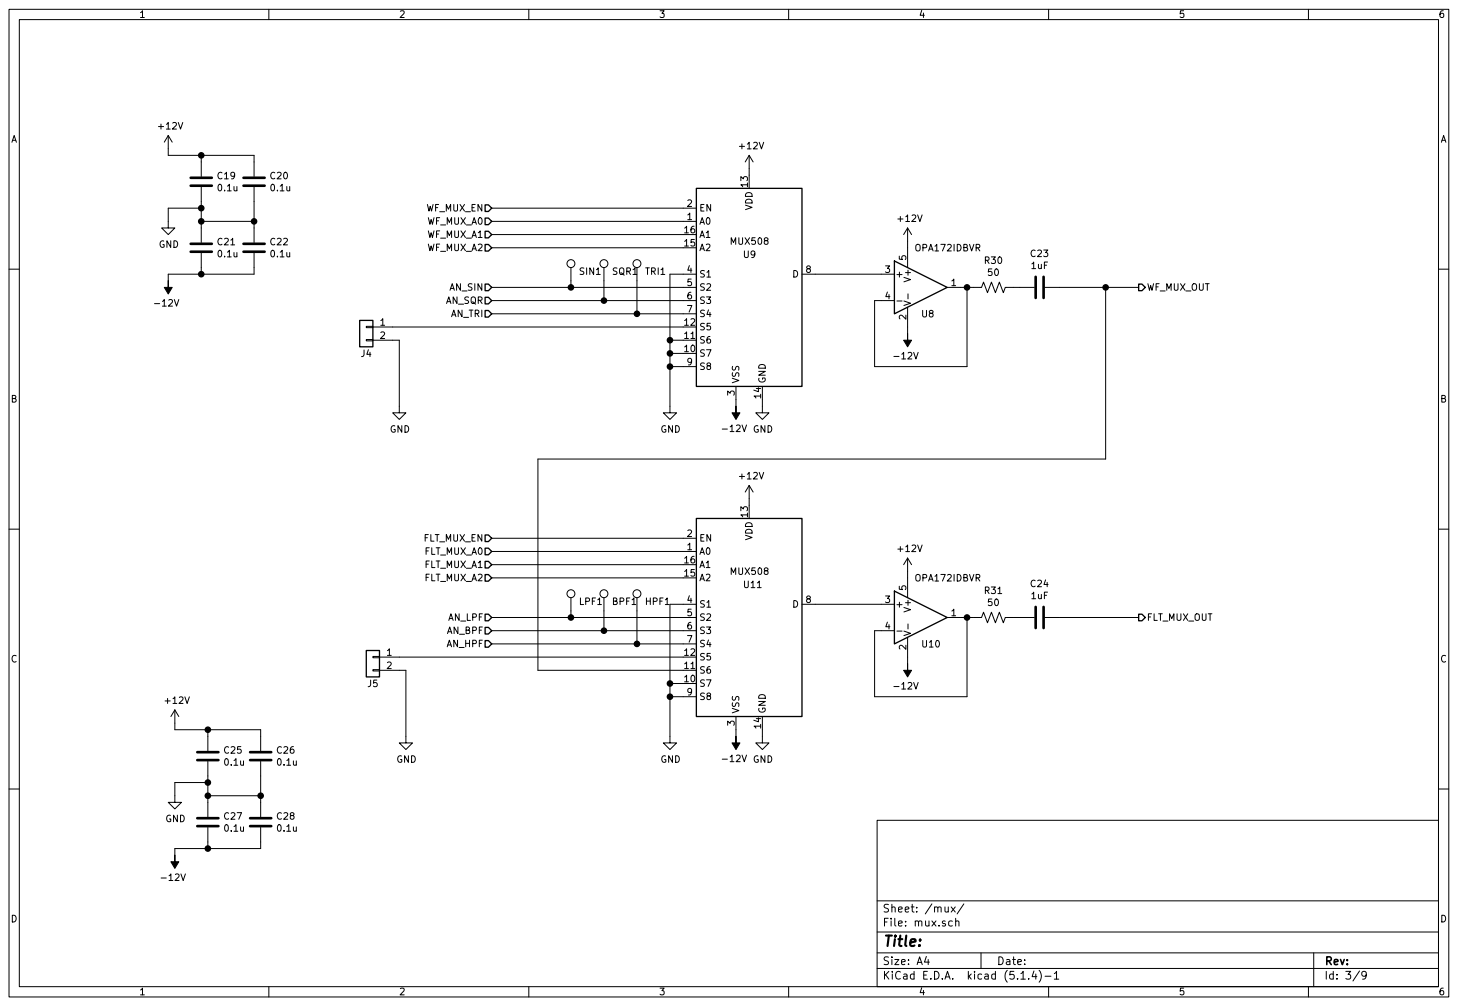
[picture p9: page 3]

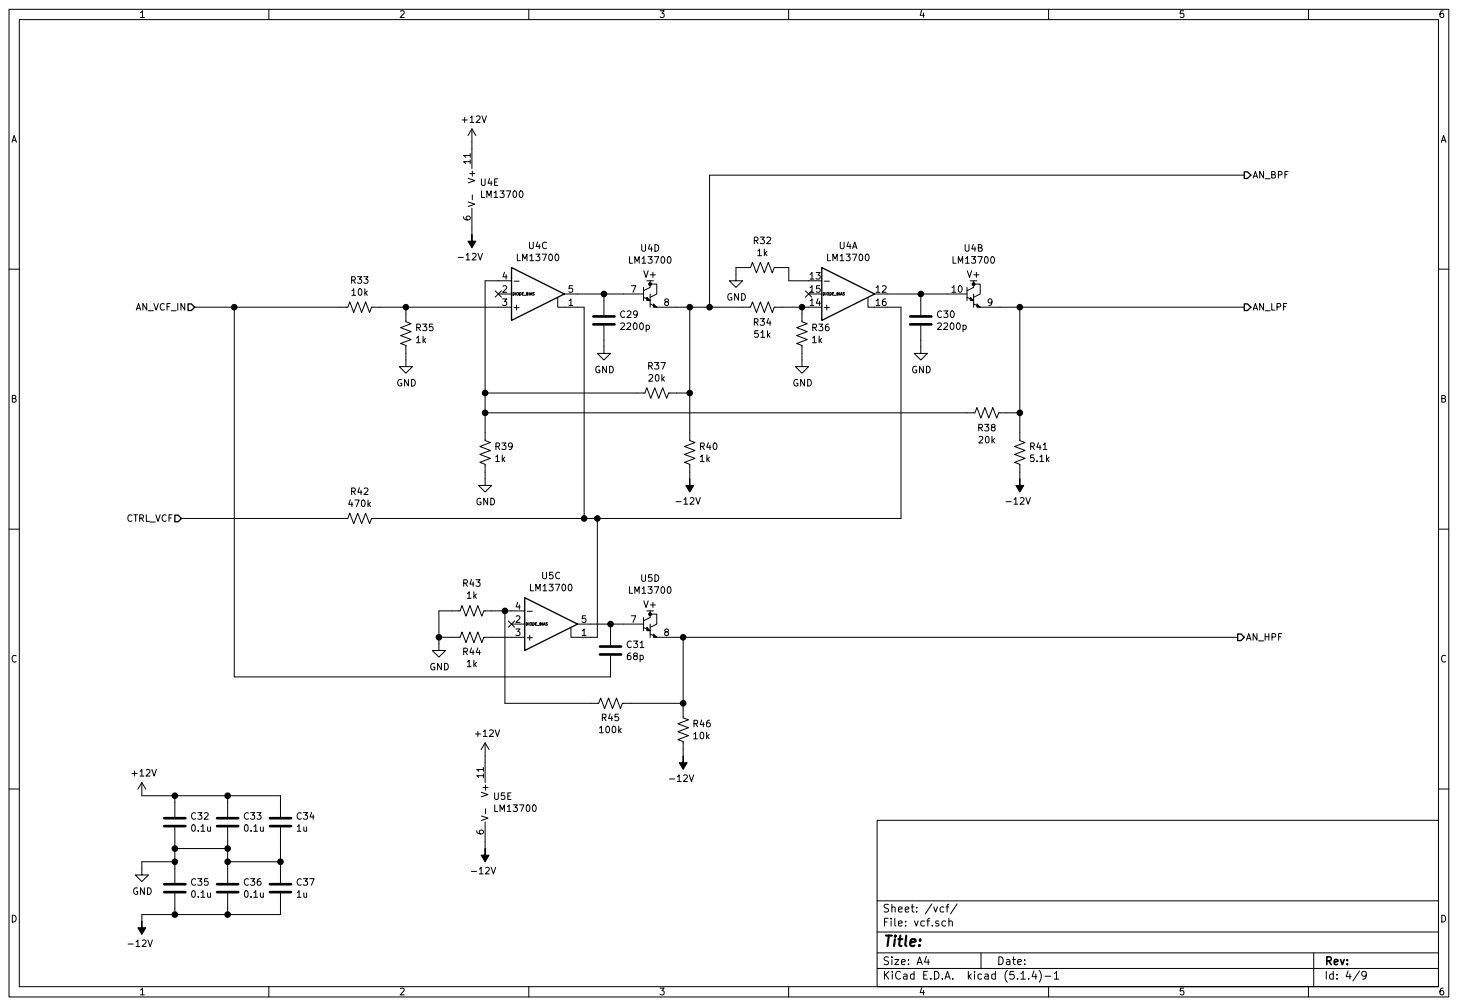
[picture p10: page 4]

Id: 4/9 Title: File: vcf.sch Sheet: /vcf/

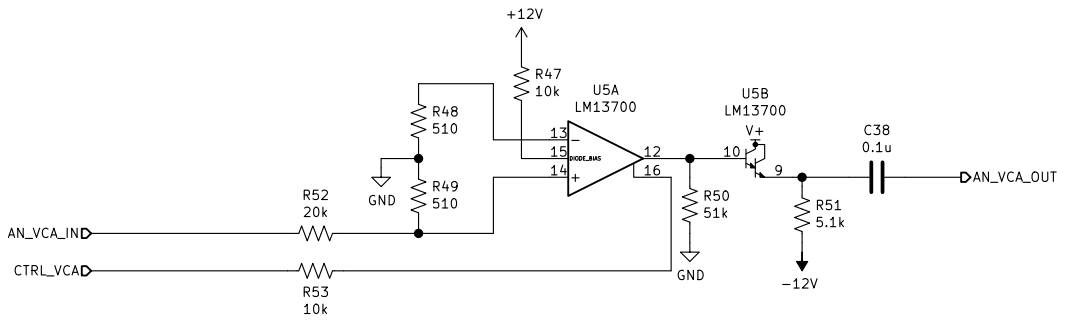
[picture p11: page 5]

Id: 5/9 Title: File: vca.sch Sheet: /vca/

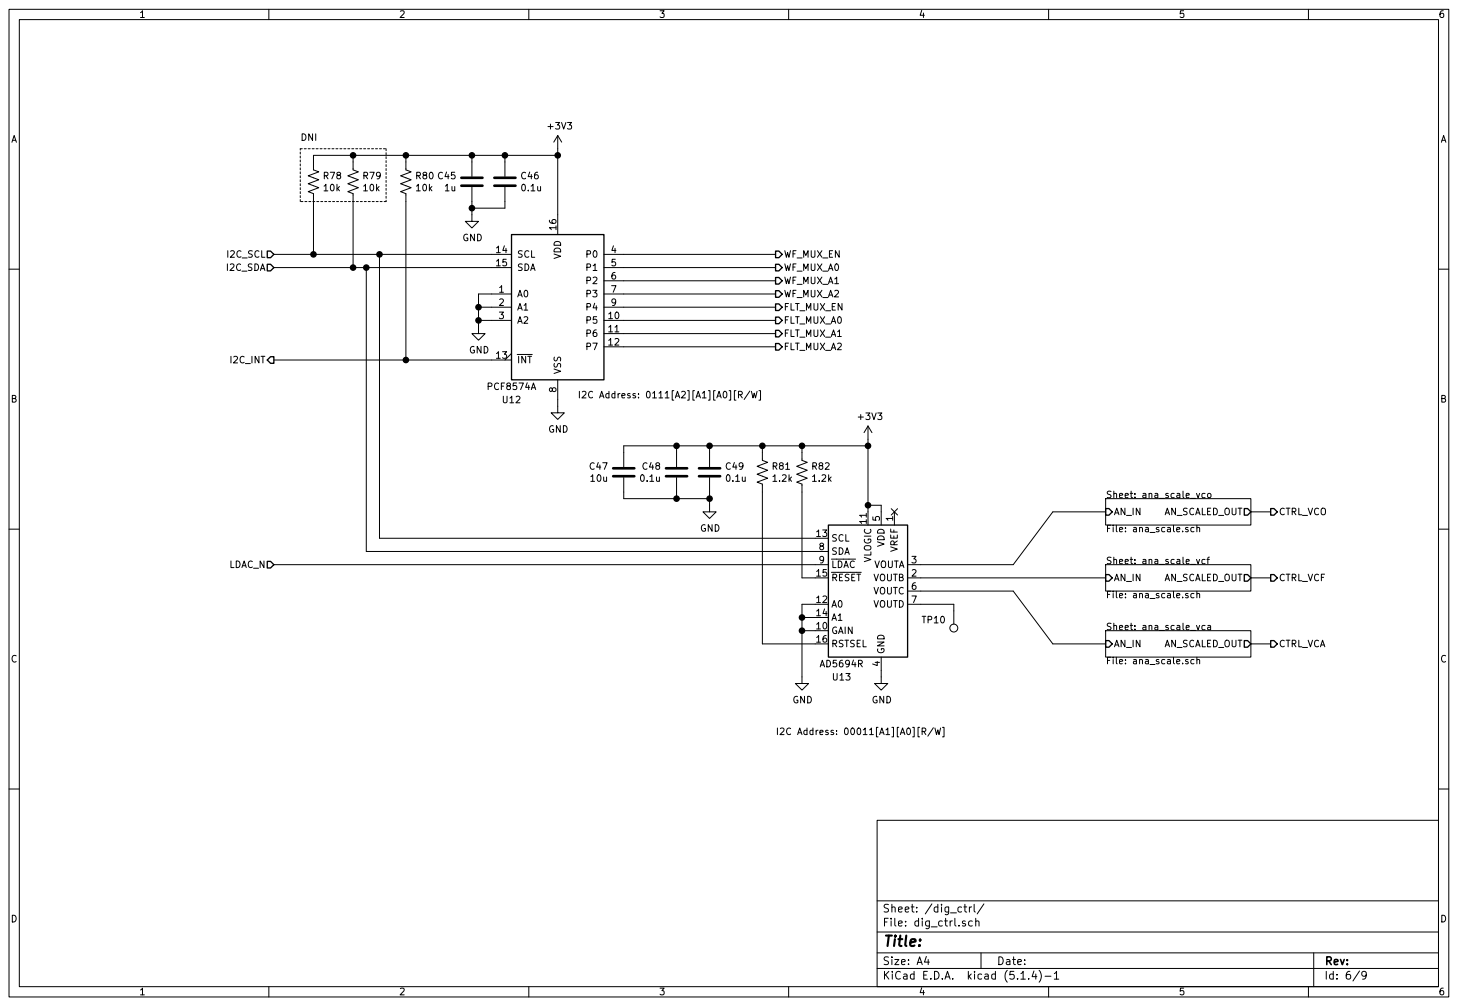
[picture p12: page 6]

1 GAIN 10 VLOGIC 11 A0 12 SCL 13 A1 14 RESET 15 RSTSEL 16 VOUTB 2 VOUTA 3 GND
LDAC 9 U13 AD5694R

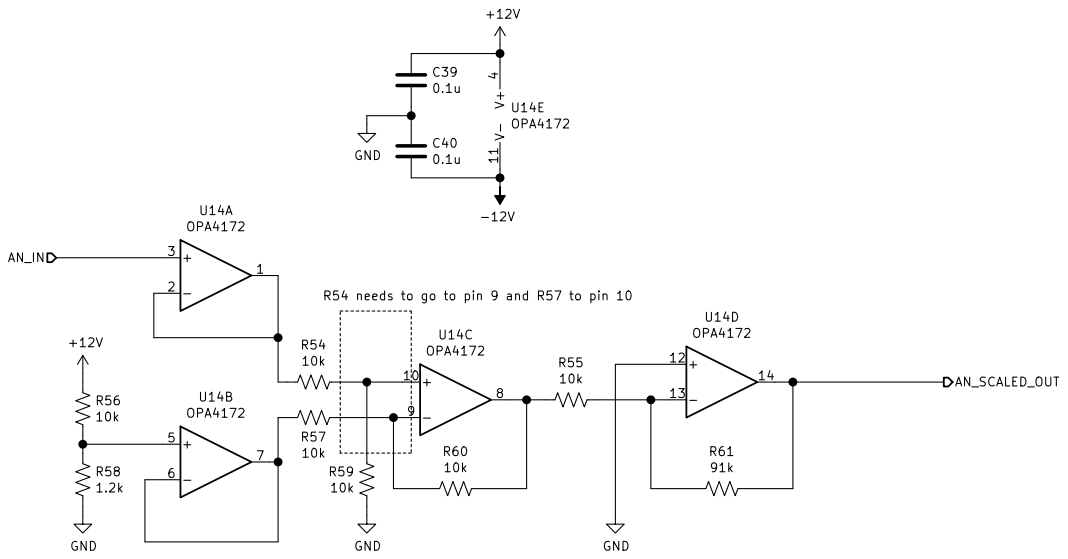
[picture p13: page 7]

AN_SCALED_OUT R54 needs to go to pin 9 and R57 to pin 10


AN_SCALED_OUT R54 needs to go to pin 9 and R57 to pin 10


AN_SCALED_OUT R54 needs to go to pin 9 and R57 to pin 10

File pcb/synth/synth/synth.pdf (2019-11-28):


Sheet: vco File: vco.sch CTRL_VCO

11 | 12
13 | 14

FLT_MUX_OUT Sheet: vcf File: vcf.sch AN_VCF_IN

File: synth.sch Sheet: /
Id: 1/9 Title:


Id: 2/9 Title: File: vco.sch Sheet: /vco/ +12V R27



Id: 4/9 Title: File: vcf.sch Sheet: /vcf/


Id: 5/9 Title: File: vca.sch Sheet: /vca/

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




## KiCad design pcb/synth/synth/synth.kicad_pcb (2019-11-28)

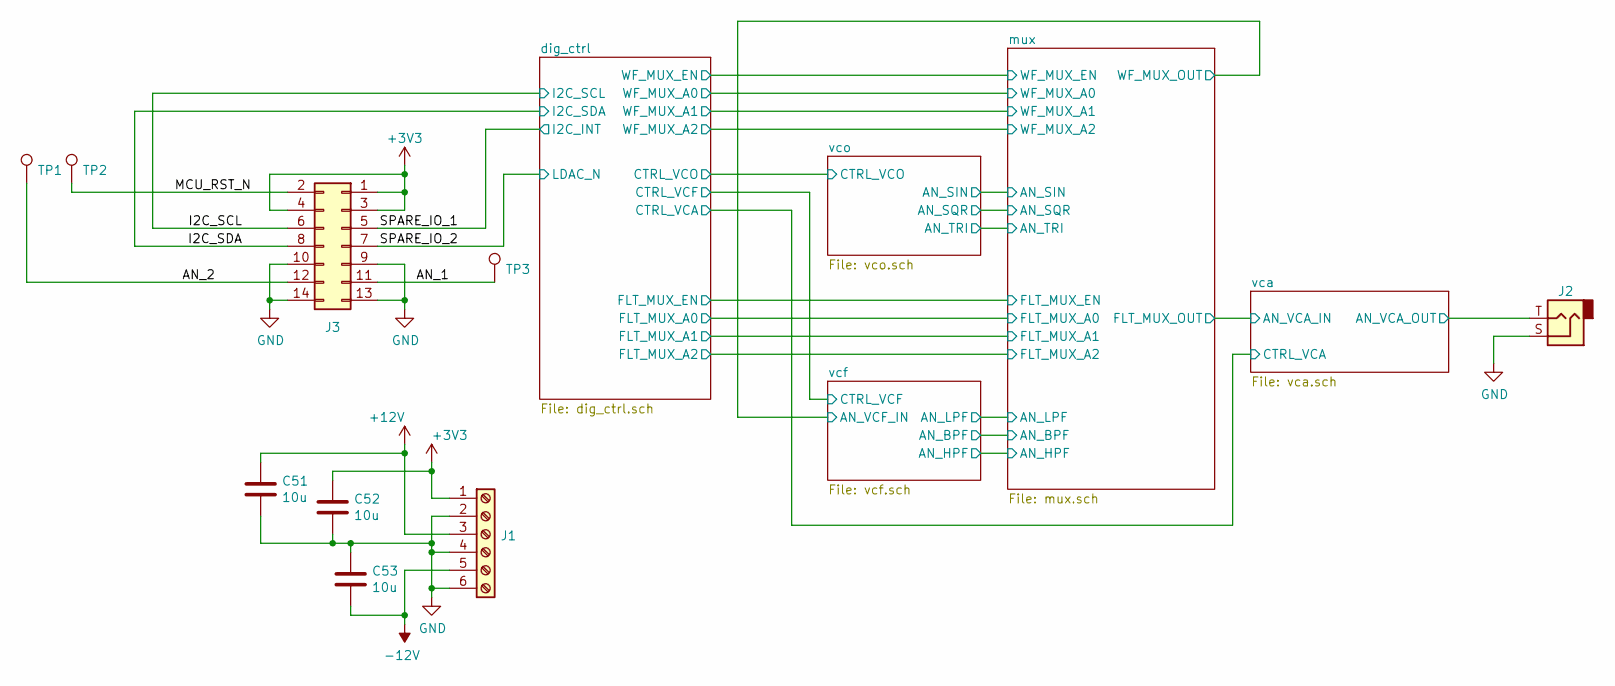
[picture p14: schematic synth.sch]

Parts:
C51, C52, C53: 10u; C_0603_1608Metric_Pad1.05x0.95mm_HandSolder
J1: Screw_Terminal_01x06; TerminalBlock_bornier-6_P5.08mm
J2: AudioJack2; PinHeader_1x02_P2.54mm_Vertical
J3: Conn_02x07_Odd_Even; PinHeader_2x07_P2.54mm_Vertical
TP1, TP2, TP3: TestPoint; TestPoint_Pad_1.0x1.0mm

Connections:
+3V3: C52.1, J1.1, J3.1, J3.3, J3.4; also elsewhere on the board
+12V: C51.1, J1.3; also elsewhere on the board
-12V: C53.2, J1.5; also elsewhere on the board
/AN_1: J3.11, TP3.1
/AN_2: J3.12, TP1.1
/I2C_SCL: J3.6; also elsewhere on the board
/I2C_SDA: J3.8; also elsewhere on the board
/MCU_RST_N: J3.2, TP2.1
/SPARE_IO_1: J3.5; also elsewhere on the board
/SPARE_IO_2: J3.7; also elsewhere on the board
/vca/AN_VCA_OUT: J2.T; also elsewhere on the board
GND: C51.2, C52.2, C53.1, J1.2, J1.4, J1.6, J2.S, J3.9, J3.10, J3.13, J3.14; also elsewhere on the board

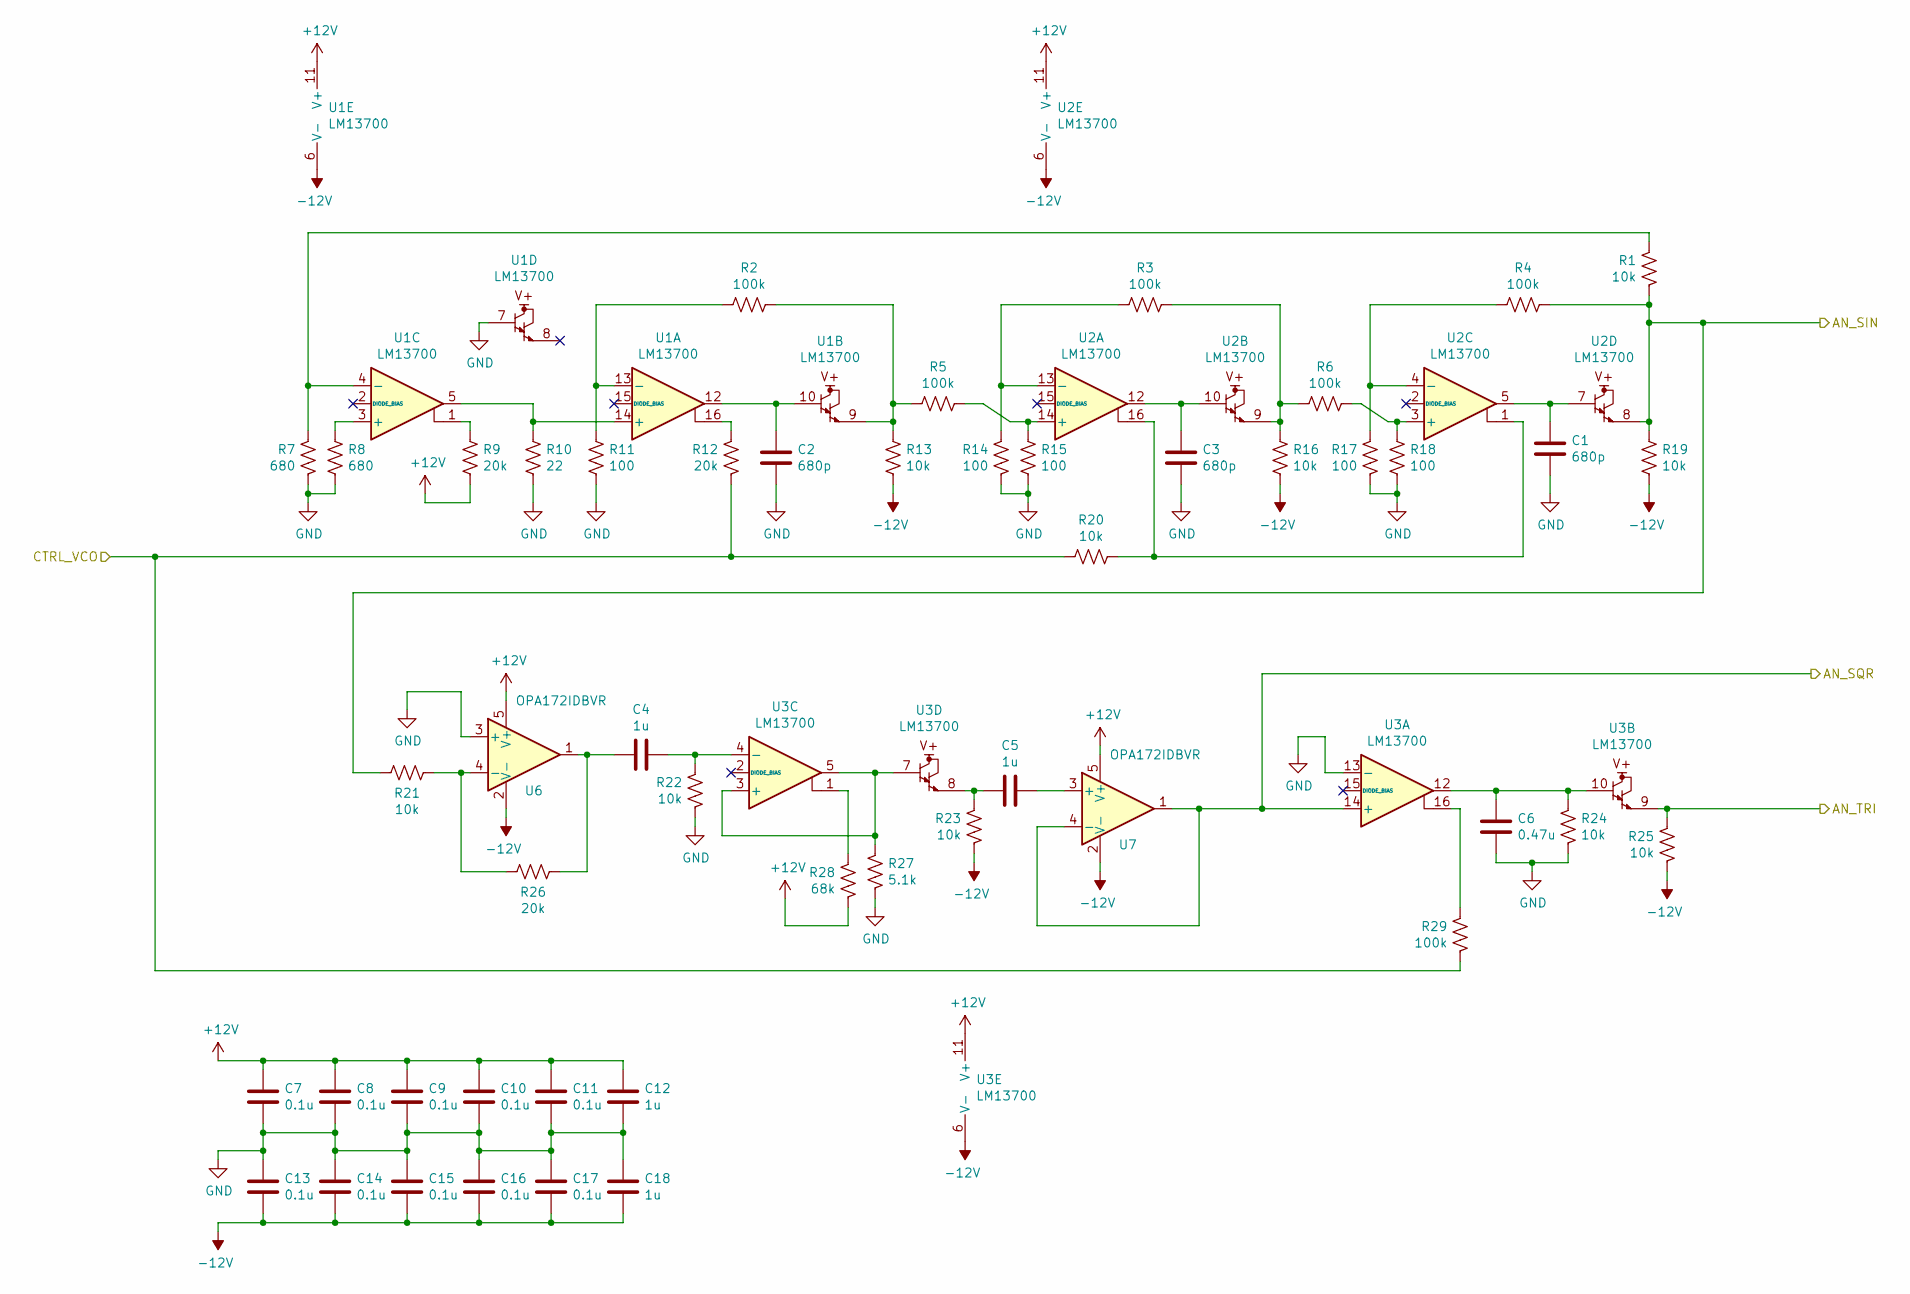
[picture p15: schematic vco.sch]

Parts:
C1, C2, C3: 680p; C_0603_1608Metric_Pad1.05x0.95mm_HandSolder
C4, C5, C12, C18: 1u; C_0603_1608Metric_Pad1.05x0.95mm_HandSolder
C6: 0.47u; C_0603_1608Metric_Pad1.05x0.95mm_HandSolder
C7, C8, C9, C10, C11, C13, C14, C15, C16, C17: 0.1u; C_0603_1608Metric_Pad1.05x0.95mm_HandSolder
R1, R13, R16, R19, R20, R21, R22, R23, R24, R25: 10k; R_0603_1608Metric_Pad1.05x0.95mm_HandSolder
R2, R3, R4, R5, R6, R29: 100k; R_0603_1608Metric_Pad1.05x0.95mm_HandSolder
R7, R8: 680; R_0603_1608Metric_Pad1.05x0.95mm_HandSolder
R9, R12, R26: 20k; R_0603_1608Metric_Pad1.05x0.95mm_HandSolder
R10: 22; R_0603_1608Metric_Pad1.05x0.95mm_HandSolder
R11, R14, R15, R17, R18: 100; R_0603_1608Metric_Pad1.05x0.95mm_HandSolder
R27: 5.1k; R_0603_1608Metric_Pad1.05x0.95mm_HandSolder
R28: 68k; R_0603_1608Metric_Pad1.05x0.95mm_HandSolder
U1, U2, U3: LM13700; SOIC-16_3.9x9.9mm_P1.27mm
U6, U7: OPA172IDBVR; SOT-23-5

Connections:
+12V: C7.1, C8.1, C9.1, C10.1, C11.1, C12.1, R9.1, R28.1, U1.11 (V+), U2.11 (V+), U3.11 (V+), U6.5 (V+), U7.5 (V+); also elsewhere on the board
-12V: C13.2, C14.2, C15.2, C16.2, C17.2, C18.2, R13.1, R16.1, R19.1, R23.1, R25.1, U1.6 (V-), U2.6 (V-), U3.6 (V-), U6.2 (V-), U7.2 (V-); also elsewhere on the board
/dig_ctrl/CTRL_VCO: R12.1, R20.2, R29.1; also elsewhere on the board
/mux/AN_SIN: R1.1, R4.1, R19.2, R21.2, U2.8; also elsewhere on the board
/mux/AN_SQR: U3.14 (+), U7.1, U7.4 (-); also elsewhere on the board
/mux/AN_TRI: R25.2, U3.9; also elsewhere on the board
GND: C1.2, C2.2, C3.2, C6.2, C7.2, C8.2, C9.2, C10.2, C11.2, C12.2, C13.1, C14.1, C15.1, C16.1, C17.1, C18.1, R7.1, R8.1, R10.1, R11.1, R14.1, R15.1, R17.1, R18.1, R22.1, R24.1, R27.1, U1.7, U3.13 (-), U6.3 (+); also elsewhere on the board
unnamed: C1.1, U2.5, U2.7
unnamed: C2.1, U1.10, U1.12
unnamed: C3.1, U2.10, U2.12
unnamed: C4.1, R26.1, U6.1
unnamed: C4.2, R22.2, U3.4 (-)
unnamed: C5.1, R23.2, U3.8
unnamed: C5.2, U7.3 (+)
unnamed: C6.1, R24.2, U3.10, U3.12
unnamed: R1.2, R7.2, U1.4 (-)
unnamed: R8.2, U1.3 (+)
unnamed: R9.2, U1.1
unnamed: R10.2, U1.5, U1.14 (+)
unnamed: R2.2, R11.2, U1.13 (-)
unnamed: R12.2, U1.16
unnamed: R2.1, R5.2, R13.2, U1.9
unnamed: R3.2, R14.2, U2.13 (-)
unnamed: R5.1, R15.2, U2.14 (+)
unnamed: R3.1, R6.2, R16.2, U2.9
unnamed: R4.2, R17.2, U2.4 (-)
unnamed: R6.1, R18.2, U2.3 (+)
unnamed: R20.1, U2.1, U2.16
unnamed: R21.1, R26.2, U6.4 (-)
unnamed: R27.2, U3.3 (+), U3.5, U3.7
unnamed: R28.2, U3.1
unnamed: R29.2, U3.16

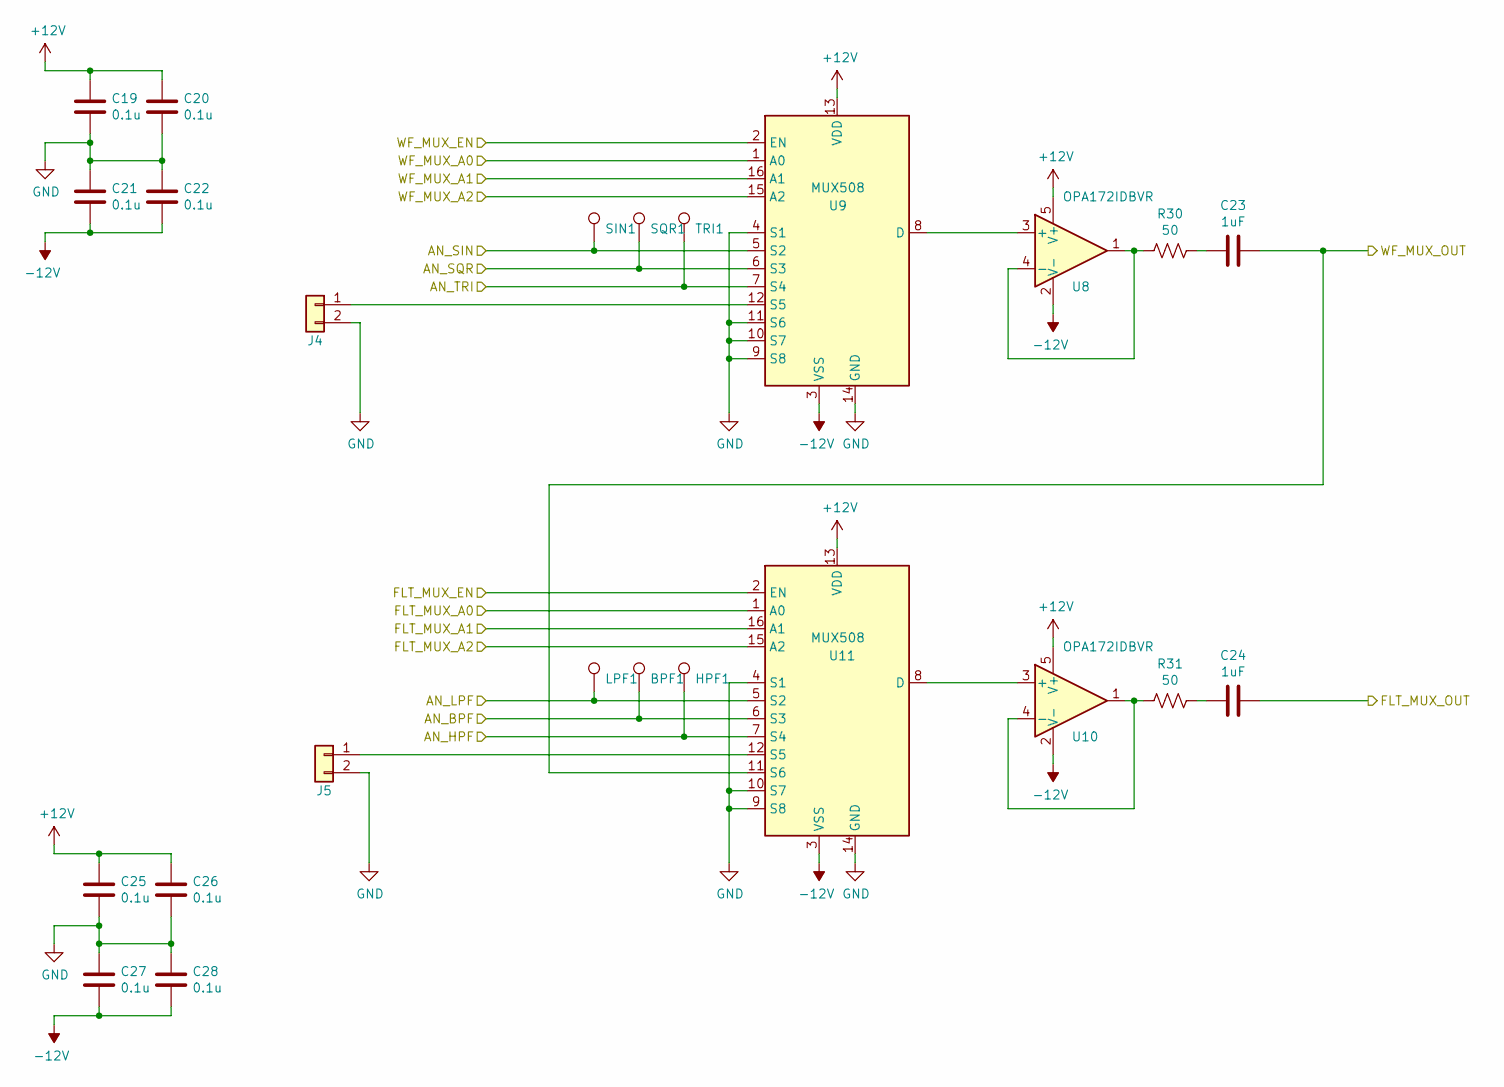
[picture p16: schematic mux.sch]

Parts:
BPF1: TestPoint; TestPoint_Pad_1.0x1.0mm
C19, C20, C21, C22, C25, C26, C27, C28: 0.1u; C_0603_1608Metric_Pad1.05x0.95mm_HandSolder
C23, C24: 1uF; C_0603_1608Metric_Pad1.05x0.95mm_HandSolder
HPF1: TestPoint; TestPoint_Pad_1.0x1.0mm
J4, J5: Conn_01x02; PinHeader_1x02_P2.54mm_Vertical
LPF1: TestPoint; TestPoint_Pad_1.0x1.0mm
R30, R31: 50; R_0603_1608Metric_Pad1.05x0.95mm_HandSolder
SIN1: TestPoint; TestPoint_Pad_1.0x1.0mm
SQR1: TestPoint; TestPoint_Pad_1.0x1.0mm
TRI1: TestPoint; TestPoint_Pad_1.0x1.0mm
U8, U10: OPA172IDBVR; SOT-23-5
U9, U11: MUX508; SOIC-16_3.9x9.9mm_P1.27mm

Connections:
+12V: C19.1, C20.1, C25.1, C26.1, U8.5 (V+), U9.13 (VDD), U10.5 (V+), U11.13 (VDD); also elsewhere on the board
-12V: C21.2, C22.2, C27.2, C28.2, U8.2 (V-), U9.3 (VSS), U10.2 (V-), U11.3 (VSS); also elsewhere on the board
/dig_ctrl/FLT_MUX_A0: U11.1 (A0); also elsewhere on the board
/dig_ctrl/FLT_MUX_A1: U11.16 (A1); also elsewhere on the board
/dig_ctrl/FLT_MUX_A2: U11.15 (A2); also elsewhere on the board
/dig_ctrl/FLT_MUX_EN: U11.2 (EN); also elsewhere on the board
/dig_ctrl/WF_MUX_A0: U9.1 (A0); also elsewhere on the board
/dig_ctrl/WF_MUX_A1: U9.16 (A1); also elsewhere on the board
/dig_ctrl/WF_MUX_A2: U9.15 (A2); also elsewhere on the board
/dig_ctrl/WF_MUX_EN: U9.2 (EN); also elsewhere on the board
/mux/AN_BPF: BPF1.1, U11.6 (S3); also elsewhere on the board
/mux/AN_HPF: HPF1.1, U11.7 (S4); also elsewhere on the board
/mux/AN_LPF: LPF1.1, U11.5 (S2); also elsewhere on the board
/mux/AN_SIN: SIN1.1, U9.5 (S2); also elsewhere on the board
/mux/AN_SQR: SQR1.1, U9.6 (S3); also elsewhere on the board
/mux/AN_TRI: TRI1.1, U9.7 (S4); also elsewhere on the board
/vca/AN_VCA_IN: C24.2; also elsewhere on the board
/vcf/AN_VCF_IN: C23.2, U11.11 (S6); also elsewhere on the board
GND: C19.2, C20.2, C21.1, C22.1, C25.2, C26.2, C27.1, C28.1, J4.2, J5.2, U9.4 (S1), U9.9 (S8), U9.10 (S7), U9.11 (S6), U9.14 (GND), U11.4 (S1), U11.9 (S8), U11.10 (S7), U11.14 (GND); also elsewhere on the board
unnamed: C23.1, R30.1
unnamed: C24.1, R31.1
unnamed: J4.1, U9.12 (S5)
unnamed: J5.1, U11.12 (S5)
unnamed: R30.2, U8.1, U8.4 (-)
unnamed: R31.2, U10.1, U10.4 (-)
unnamed: U8.3 (+), U9.8 (D)
unnamed: U10.3 (+), U11.8 (D)

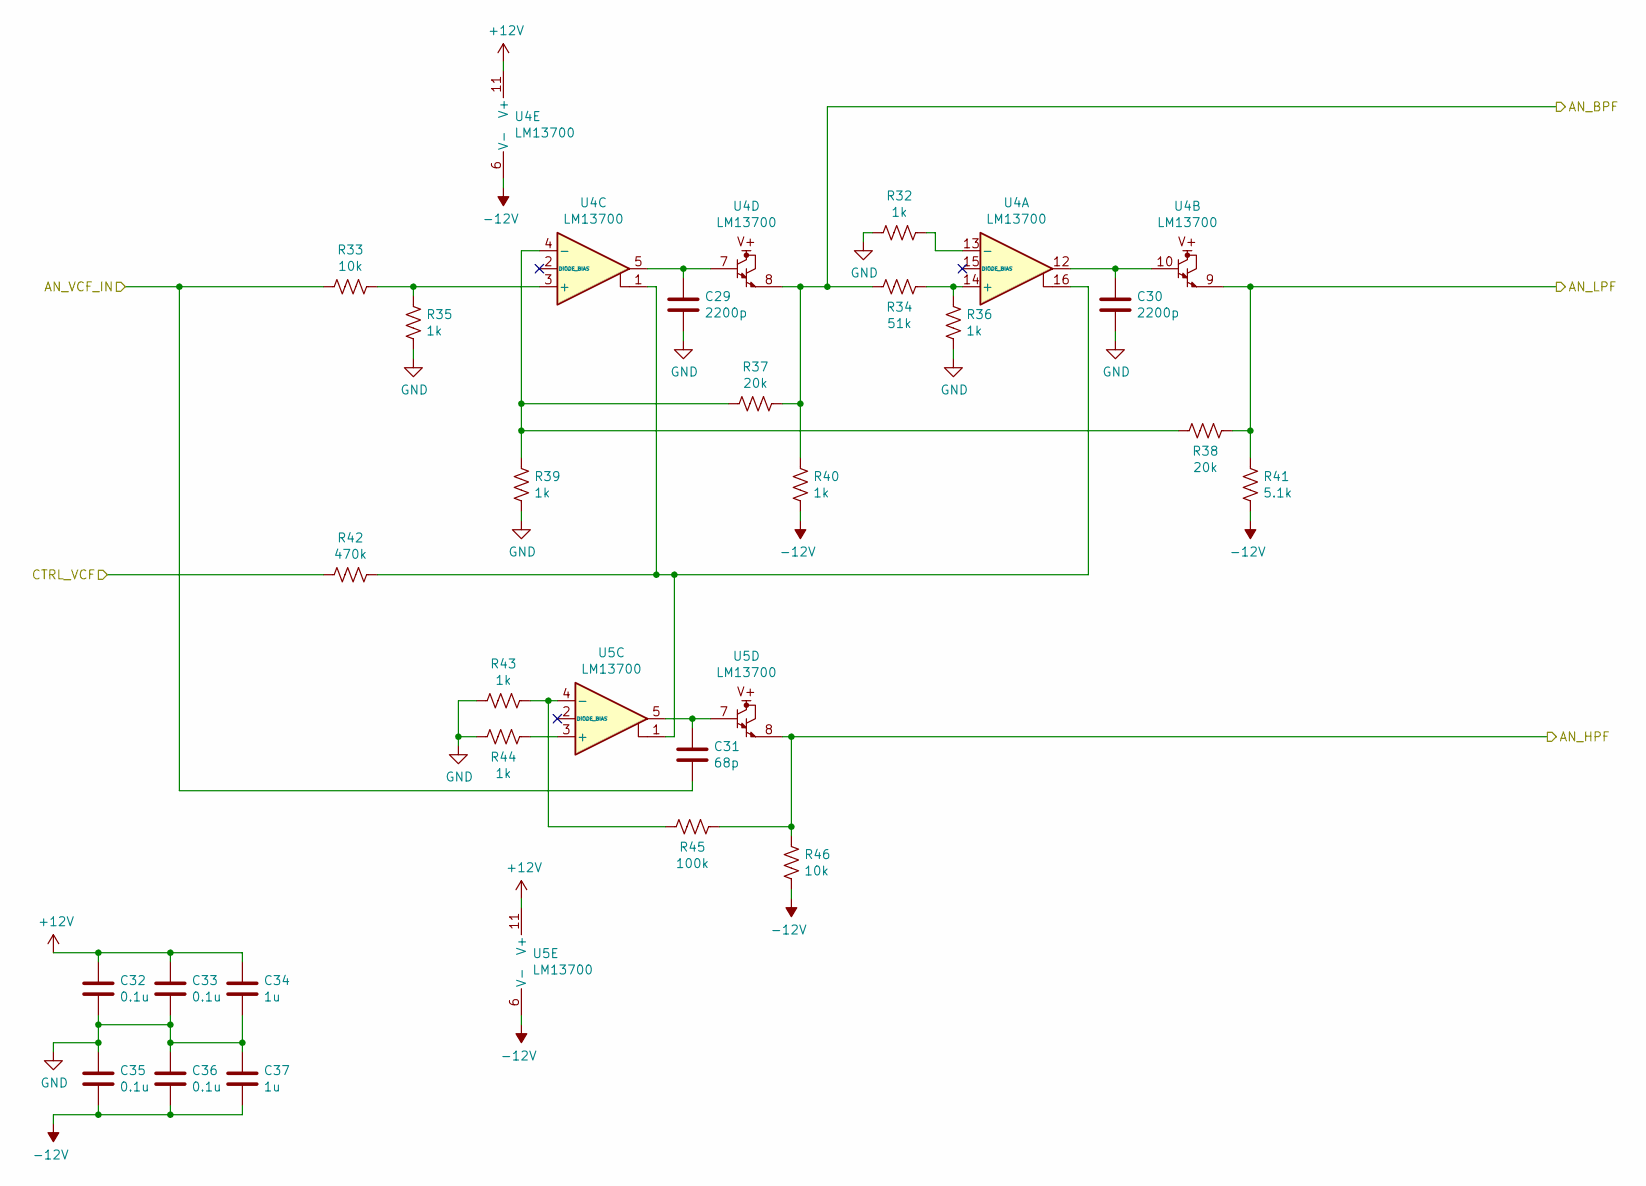
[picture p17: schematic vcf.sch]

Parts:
C29, C30: 2200p; C_0603_1608Metric_Pad1.05x0.95mm_HandSolder
C31: 68p; C_0603_1608Metric_Pad1.05x0.95mm_HandSolder
C32, C33, C35, C36: 0.1u; C_0603_1608Metric_Pad1.05x0.95mm_HandSolder
C34, C37: 1u; C_0603_1608Metric_Pad1.05x0.95mm_HandSolder
R32, R35, R36, R39, R40, R43, R44: 1k; R_0603_1608Metric_Pad1.05x0.95mm_HandSolder
R33, R46: 10k; R_0603_1608Metric_Pad1.05x0.95mm_HandSolder
R34: 51k; R_0603_1608Metric_Pad1.05x0.95mm_HandSolder
R37, R38: 20k; R_0603_1608Metric_Pad1.05x0.95mm_HandSolder
R41: 5.1k; R_0603_1608Metric_Pad1.05x0.95mm_HandSolder
R42: 470k; R_0603_1608Metric_Pad1.05x0.95mm_HandSolder
R45: 100k; R_0603_1608Metric_Pad1.05x0.95mm_HandSolder
U4, U5: LM13700; SOIC-16_3.9x9.9mm_P1.27mm

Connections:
+12V: C32.1, C33.1, C34.1, U4.11 (V+), U5.11 (V+); also elsewhere on the board
-12V: C35.2, C36.2, C37.2, R40.2, R41.2, R46.2, U4.6 (V-), U5.6 (V-); also elsewhere on the board
/dig_ctrl/CTRL_VCF: R42.2; also elsewhere on the board
/mux/AN_BPF: R34.2, R37.1, R40.1, U4.8; also elsewhere on the board
/mux/AN_HPF: R45.2, R46.1, U5.8; also elsewhere on the board
/mux/AN_LPF: R38.1, R41.1, U4.9; also elsewhere on the board
/vcf/AN_VCF_IN: C31.2, R33.2; also elsewhere on the board
GND: C29.2, C30.2, C32.2, C33.2, C34.2, C35.1, C36.1, C37.1, R32.2, R35.2, R36.2, R39.2, R43.1, R44.1; also elsewhere on the board
unnamed: C29.1, U4.5, U4.7
unnamed: C30.1, U4.10, U4.12
unnamed: C31.1, U5.5, U5.7
unnamed: R32.1, U4.13 (-)
unnamed: R33.1, R35.1, U4.3 (+)
unnamed: R34.1, R36.1, U4.14 (+)
unnamed: R37.2, R38.2, R39.1, U4.4 (-)
unnamed: R42.1, U4.1, U4.16, U5.1
unnamed: R43.2, R45.1, U5.4 (-)
unnamed: R44.2, U5.3 (+)

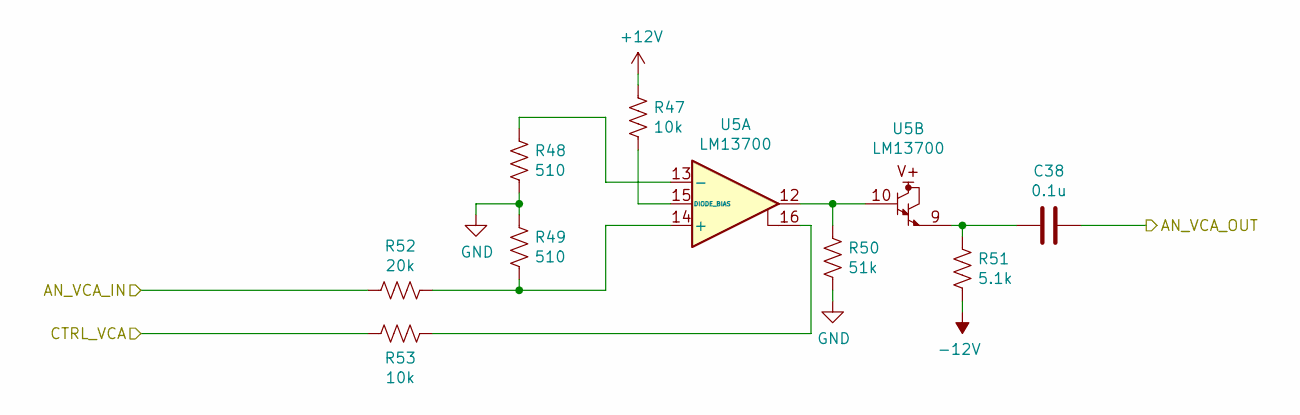
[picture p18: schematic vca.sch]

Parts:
C38: 0.1u; C_0603_1608Metric_Pad1.05x0.95mm_HandSolder
R47, R53: 10k; R_0603_1608Metric_Pad1.05x0.95mm_HandSolder
R48, R49: 510; R_0603_1608Metric_Pad1.05x0.95mm_HandSolder
R50: 51k; R_0603_1608Metric_Pad1.05x0.95mm_HandSolder
R51: 5.1k; R_0603_1608Metric_Pad1.05x0.95mm_HandSolder
R52: 20k; R_0603_1608Metric_Pad1.05x0.95mm_HandSolder
U5: LM13700; SOIC-16_3.9x9.9mm_P1.27mm

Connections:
+12V: R47.2; also elsewhere on the board
-12V: R51.1; also elsewhere on the board
/dig_ctrl/CTRL_VCA: R53.2; also elsewhere on the board
/vca/AN_VCA_IN: R52.2; also elsewhere on the board
/vca/AN_VCA_OUT: C38.1; also elsewhere on the board
GND: R48.1, R49.2, R50.1; also elsewhere on the board
unnamed: C38.2, R51.2, U5.9
unnamed: R47.1, U5.15 (DIODE_BIAS)
unnamed: R48.2, U5.13 (-)
unnamed: R49.1, R52.1, U5.14 (+)
unnamed: R50.2, U5.10, U5.12
unnamed: R53.1, U5.16

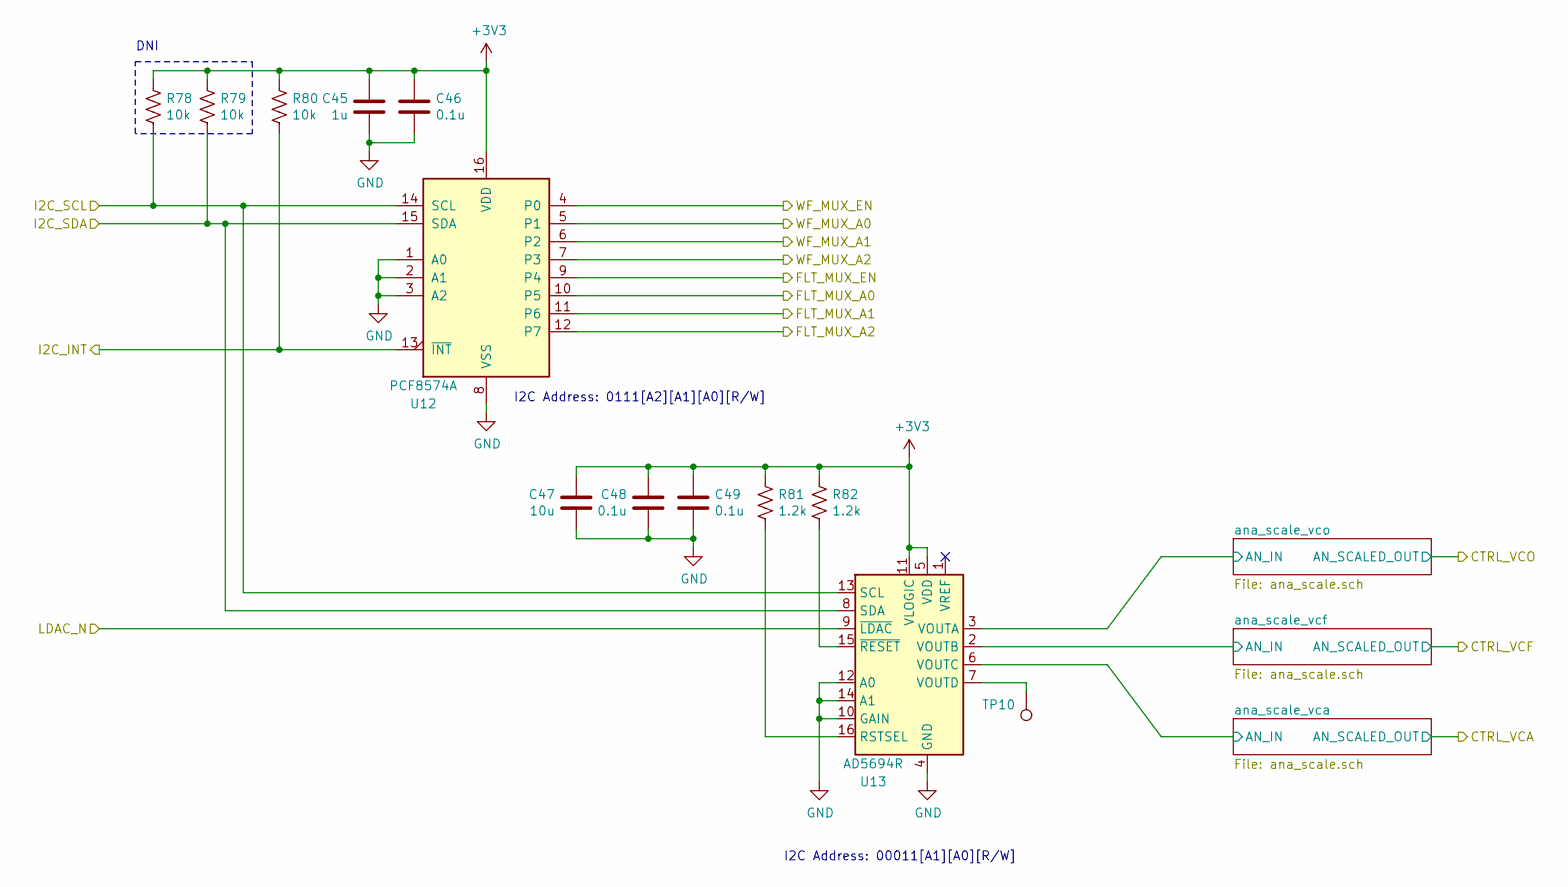
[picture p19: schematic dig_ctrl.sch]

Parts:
C45: 1u; C_0603_1608Metric_Pad1.05x0.95mm_HandSolder
C46, C48, C49: 0.1u; C_0603_1608Metric_Pad1.05x0.95mm_HandSolder
C47: 10u; C_0603_1608Metric_Pad1.05x0.95mm_HandSolder
R78, R79, R80: 10k; R_0603_1608Metric_Pad1.05x0.95mm_HandSolder
R81, R82: 1.2k; R_0603_1608Metric_Pad1.05x0.95mm_HandSolder
TP10: TestPoint; TestPoint_Pad_1.0x1.0mm
U12: PCF8574A; SOIC-16W_7.5x10.3mm_P1.27mm
U13: AD5694R; TSSOP-16_4.4x5mm_P0.65mm

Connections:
+3V3: C45.1, C46.1, C47.1, C48.1, C49.1, R78.1, R79.1, R80.1, R81.1, R82.1, U12.16 (VDD), U13.5 (VDD), U13.11 (VLOGIC); also elsewhere on the board
/I2C_SCL: R78.2, U12.14 (SCL), U13.13 (SCL); also elsewhere on the board
/I2C_SDA: R79.2, U12.15 (SDA), U13.8 (SDA); also elsewhere on the board
/SPARE_IO_1: R80.2, U12.13 (~INT~); also elsewhere on the board
/SPARE_IO_2: U13.9 (~LDAC); also elsewhere on the board
/dig_ctrl/FLT_MUX_A0: U12.10 (P5); also elsewhere on the board
/dig_ctrl/FLT_MUX_A1: U12.11 (P6); also elsewhere on the board
/dig_ctrl/FLT_MUX_A2: U12.12 (P7); also elsewhere on the board
/dig_ctrl/FLT_MUX_EN: U12.9 (P4); also elsewhere on the board
/dig_ctrl/WF_MUX_A0: U12.5 (P1); also elsewhere on the board
/dig_ctrl/WF_MUX_A1: U12.6 (P2); also elsewhere on the board
/dig_ctrl/WF_MUX_A2: U12.7 (P3); also elsewhere on the board
/dig_ctrl/WF_MUX_EN: U12.4 (P0); also elsewhere on the board
/dig_ctrl/ana_scale_vca/AN_IN: U13.6 (VOUTC); also elsewhere on the board
/dig_ctrl/ana_scale_vcf/AN_IN: U13.2 (VOUTB); also elsewhere on the board
/dig_ctrl/ana_scale_vco/AN_IN: U13.3 (VOUTA); also elsewhere on the board
GND: C45.2, C46.2, C47.2, C48.2, C49.2, U12.1 (A0), U12.2 (A1), U12.3 (A2), U12.8 (VSS), U13.4 (GND), U13.10 (GAIN), U13.12 (A0), U13.14 (A1); also elsewhere on the board
unnamed: R81.2, U13.16 (RSTSEL)
unnamed: R82.2, U13.15 (~RESET)
unnamed: TP10.1, U13.7 (VOUTD)

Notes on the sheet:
I2C Address: 0111[A2][A1][A0][R/W]
I2C Address: 00011[A1][A0][R/W]
DNI

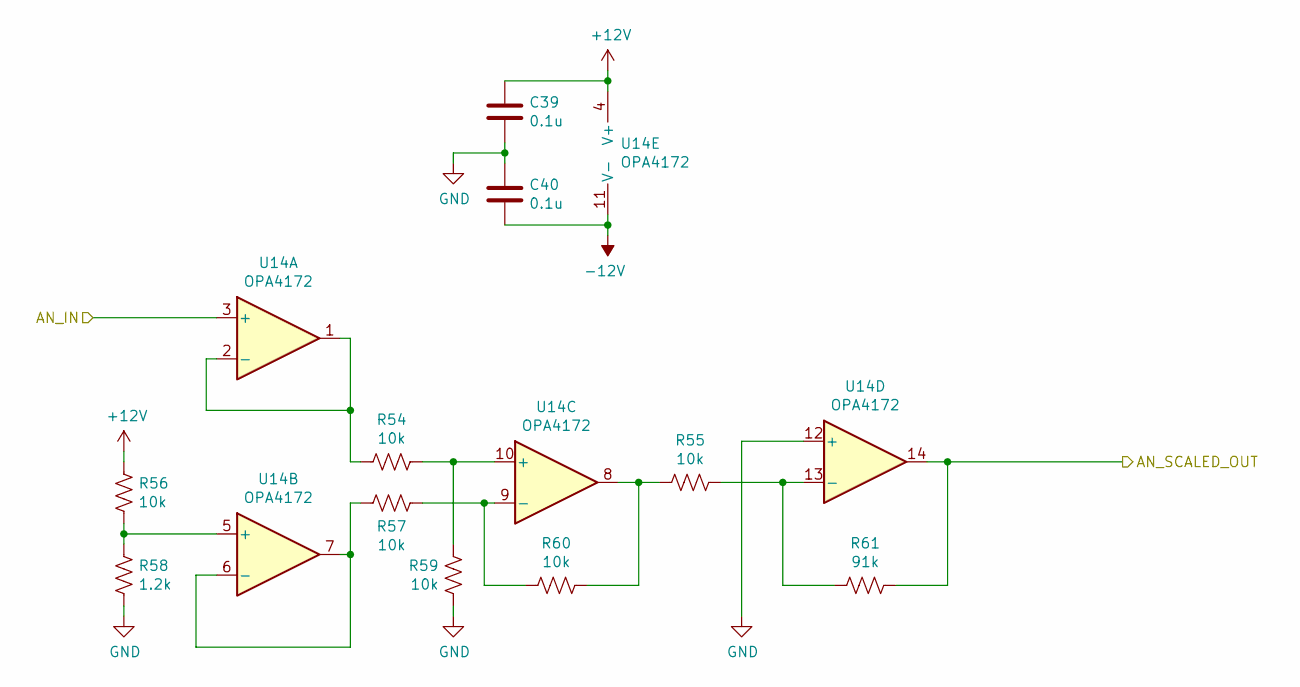
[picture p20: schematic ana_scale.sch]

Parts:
C39, C40: 0.1u; C_0603_1608Metric_Pad1.05x0.95mm_HandSolder
R54, R55, R56, R57, R59, R60: 10k; R_0603_1608Metric_Pad1.05x0.95mm_HandSolder
R58: 1.2k; R_0603_1608Metric_Pad1.05x0.95mm_HandSolder
R61: 91k; R_0603_1608Metric_Pad1.05x0.95mm_HandSolder
U14: OPA4172; SOIC-14_3.9x8.7mm_P1.27mm

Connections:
+12V: C39.1, R56.1, U14.4 (V+); also elsewhere on the board
-12V: C40.2, U14.11 (V-); also elsewhere on the board
/dig_ctrl/CTRL_VCO: R61.2, U14.14; also elsewhere on the board
/dig_ctrl/ana_scale_vco/AN_IN: U14.3 (+); also elsewhere on the board
GND: C39.2, C40.1, R58.2, R59.2, U14.12 (+); also elsewhere on the board
unnamed: R54.1, U14.1, U14.2 (-)
unnamed: R54.2, R59.1, U14.10 (+)
unnamed: R55.1, R60.2, U14.8
unnamed: R55.2, R61.1, U14.13 (-)
unnamed: R56.2, R58.1, U14.5 (+)
unnamed: R57.1, U14.6 (-), U14.7
unnamed: R57.2, R60.1, U14.9 (-)

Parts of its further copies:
C41, C42, C43, C44: 0.1u; C_0603_1608Metric_Pad1.05x0.95mm_HandSolder
R62, R63, R64, R65, R67, R68, R70, R71, R72, R73, R75, R76: 10k; R_0603_1608Metric_Pad1.05x0.95mm_HandSolder
R66, R74: 1.2k; R_0603_1608Metric_Pad1.05x0.95mm_HandSolder
U15, U16: OPA4172; SOIC-14_3.9x8.7mm_P1.27mm

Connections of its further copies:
+12V: C41.1, C43.1, R64.1, R72.1, U15.4 (V+), U16.4 (V+); also elsewhere on the board
-12V: C42.2, C44.2, U15.11 (V-), U16.11 (V-); also elsewhere on the board
/dig_ctrl/CTRL_VCA: U16.14; also elsewhere on the board
/dig_ctrl/CTRL_VCF: U15.14; also elsewhere on the board
/dig_ctrl/ana_scale_vca/AN_IN: U16.3 (+); also elsewhere on the board
/dig_ctrl/ana_scale_vcf/AN_IN: U15.3 (+); also elsewhere on the board
GND: C41.2, C42.1, C43.2, C44.1, R66.2, R67.2, R74.2, R75.2, U15.12 (+), U16.12 (+); also elsewhere on the board
unnamed: R62.1, U15.1, U15.2 (-)
unnamed: R62.2, R67.1, U15.10 (+)
unnamed: R63.1, R68.2, U15.8
unnamed 91: R63.2, U15.13 (-); also elsewhere on the board
unnamed: R64.2, R66.1, U15.5 (+)
unnamed: R65.1, U15.6 (-), U15.7
unnamed: R65.2, R68.1, U15.9 (-)
unnamed: R70.1, U16.1, U16.2 (-)
unnamed: R70.2, R75.1, U16.10 (+)
unnamed: R71.1, R76.2, U16.8
unnamed 98: R71.2, U16.13 (-); also elsewhere on the board
unnamed: R72.2, R74.1, U16.5 (+)
unnamed: R73.1, U16.6 (-), U16.7
unnamed: R73.2, R76.1, U16.9 (-)

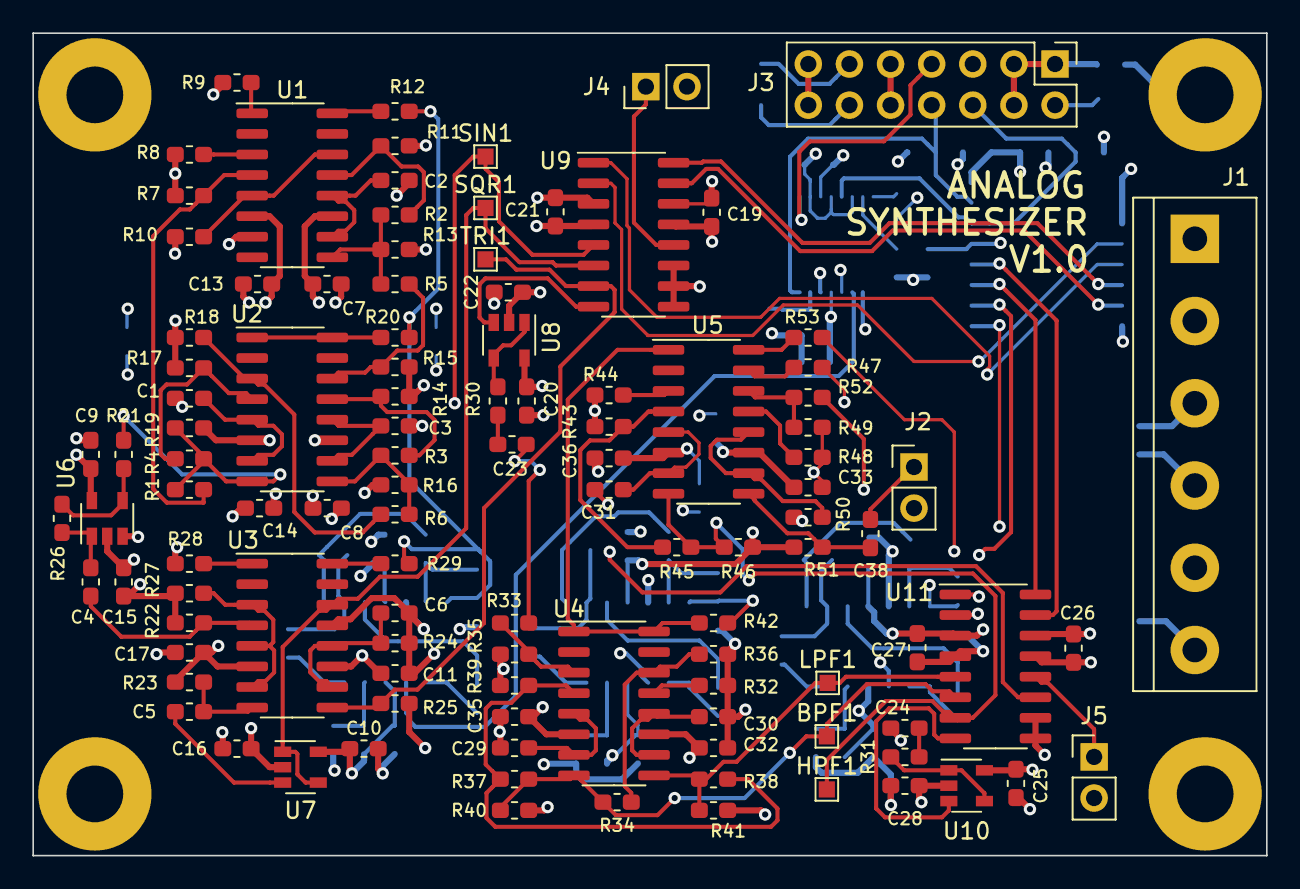
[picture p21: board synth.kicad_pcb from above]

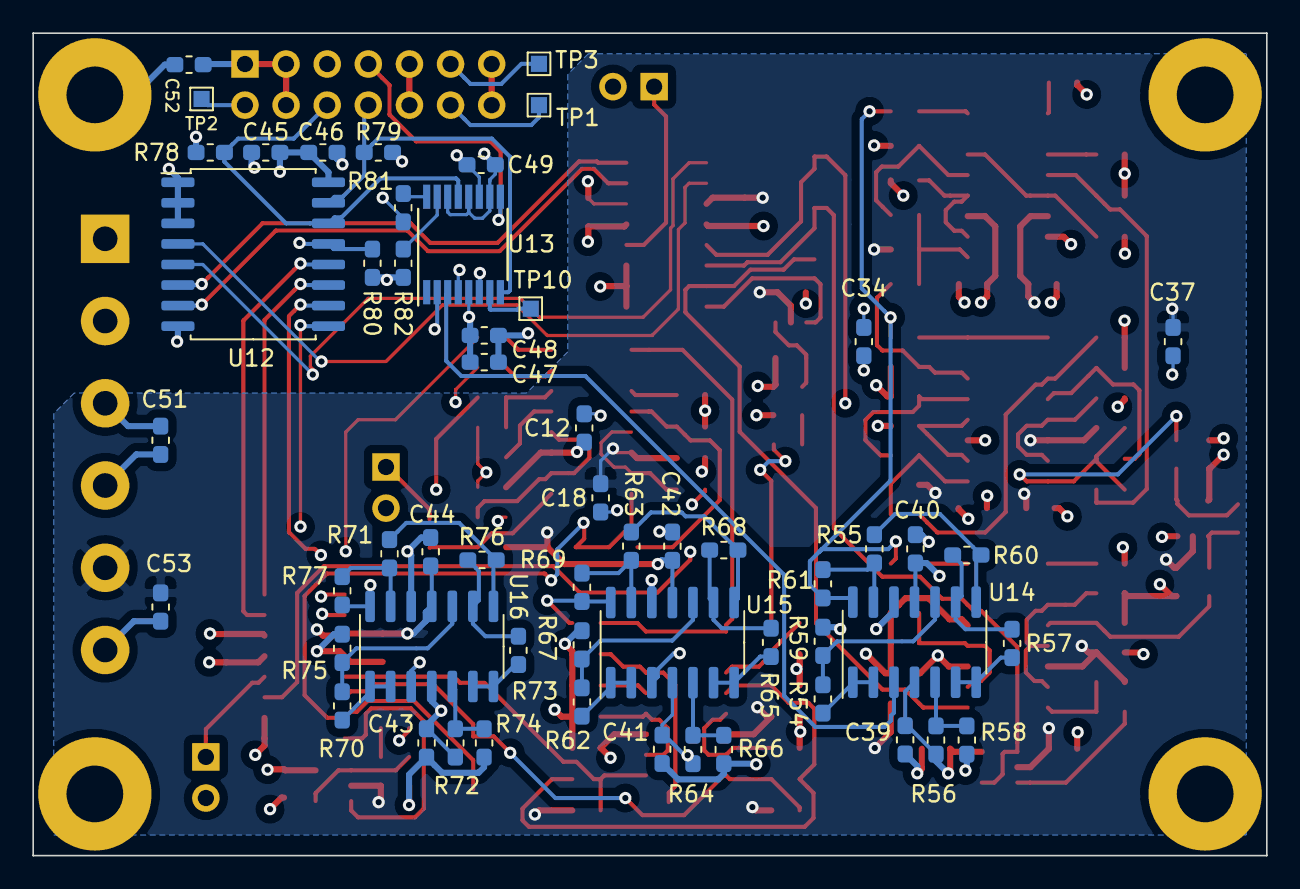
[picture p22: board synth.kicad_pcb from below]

Board: 4 copper layers, 76.2 x 50.8 mm, 165 parts (56 on the bottom side), 107 nets.

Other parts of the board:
R69, R77: 10k; R_0603_1608Metric_Pad1.05x0.95mm_HandSolder

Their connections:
/dig_ctrl/CTRL_VCA: R77.2; also elsewhere on the board
/dig_ctrl/CTRL_VCF: R69.2; also elsewhere on the board
unnamed 91: R69.1; also elsewhere on the board
unnamed 98: R77.1; also elsewhere on the board

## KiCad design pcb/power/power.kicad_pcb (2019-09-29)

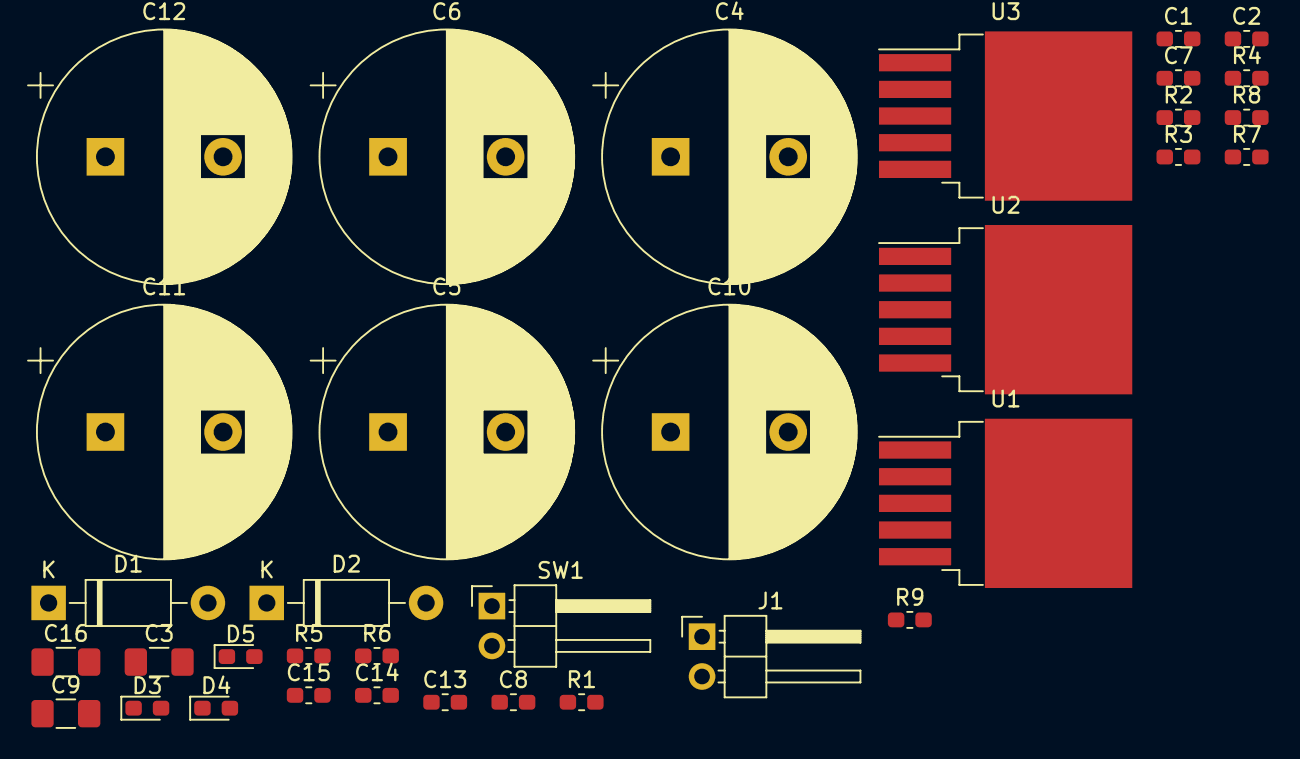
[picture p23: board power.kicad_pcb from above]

Board: 2 copper layers, 35 parts (0 on the bottom side), 14 nets, no tracks yet.

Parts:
C1, C2, C7, C8, C13, C15: 1uF; C_0603_1608Metric_Pad1.05x0.95mm_HandSolder
C3, C9, C16: 10uF; C_1206_3216Metric_Pad1.42x1.75mm_HandSolder
C4, C5, C6, C10, C11, C12: 3300uF; CP_Radial_D16.0mm_P7.50mm
C14: 10nF; C_0603_1608Metric_Pad1.05x0.95mm_HandSolder
D1, D2: 1N4004; D_DO-41_SOD81_P10.16mm_Horizontal
D3, D4, D5: LED; LED_0603_1608Metric_Pad1.05x0.95mm_HandSolder
J1: Barrel_Jack; PinHeader_1x02_P2.54mm_Horizontal
R1: 330k; R_0603_1608Metric_Pad1.05x0.95mm_HandSolder
R2, R4, R6: 12.1k; R_0603_1608Metric_Pad1.05x0.95mm_HandSolder
R3: 1.2Meg; R_0603_1608Metric_Pad1.05x0.95mm_HandSolder
R5: 107K; R_0603_1608Metric_Pad1.05x0.95mm_HandSolder
R7: 330; R_0603_1608Metric_Pad1.05x0.95mm_HandSolder
R8, R9: 1k; R_0603_1608Metric_Pad1.05x0.95mm_HandSolder
SW1: SW_SPST; PinHeader_1x02_P2.54mm_Horizontal
U1, U2: LT3080xQ; TO-263-5_TabPin3
U3: LT3015Q; TO-263-5_TabPin3

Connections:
+3V3: C2.1, C3.1, D3.2, R2.1, U1.3
+12V: C8.1, C9.1, D4.2, R4.1, U2.3
-12V: C14.1, C15.1, C16.1, D5.1, R5.1, U3.5
/12VAC: J1.1, SW1.1
/12VAC_SW: D1.2, D2.1, SW1.2
/N12VAC_RECT: C10.1, C11.1, C12.1, C13.1, D2.2, U3.1, U3.3
/P12VAC_RECT: C1.1, C4.1, C5.1, C6.1, C7.1, D1.1, U1.4, U1.5, U2.4, U2.5
GND: C1.2, C2.2, C3.2, C4.2, C5.2, C6.2, C7.2, C8.2, C9.2, C10.2, C11.2, C12.2, C13.2, C15.2, C16.2, J1.2, R1.2, R2.2, R3.2, R4.2, R6.2, R7.1, R8.1, R9.1, U3.2
unnamed: C14.2, R5.2, R6.1, U3.4
unnamed: D3.1, R7.2
unnamed: D4.1, R8.2
unnamed: D5.2, R9.2
unnamed: R1.1, U1.2
unnamed: R3.1, U2.2

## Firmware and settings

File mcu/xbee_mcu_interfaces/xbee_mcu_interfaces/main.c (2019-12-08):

/*
 * xbee_mcu_interfaces.c
 *
 * Created: 9/25/2019 7:19:34 PM
 * Author : tyler
 */ 

/****** COMPILER VARIABLES ******/
#define _ECHO    0
#define _GLOVE   0
#define _UART_ON 0

/****** GLOBAL DEFINITIONS ******/
// 2 MHz clock - 16 MHz external crystal w/ divide by 8 fuse enabled
#define F_CPU 2000000UL

#if _GLOVE
	#define UBRR  F_CPU/16/BAUD-1
#endif

/****** INCLUDE FILES ******/
#include <avr/io.h>
#include <avr/interrupt.h>
#include <util/delay.h>
#include <string.h>
#include "../../spi/spi.h"
#include "../../xbee/xbee.h"
#include "../../xbee/api_frame.h"
#include "../../i2c/i2c.h"
#include "../../io/mcu_io.h"

#if _UART_ON
	#include "../../uart/uart.h"
#endif

#if _GLOVE
	#include "../../i2c/LSM6DS3.h"
	#include "../../io/adc.h"
#else
	#include "../../i2c/AD5694.h"
	#include "../../i2c/PCF8574.h"
#endif

/***** GLOBAL VARIABLES ******/
uint8_t  btn0_flag     = 0;
uint8_t  btn1_flag     = 0;
uint8_t  btn2_flag     = 0;
uint8_t  btn3_flag     = 0;
uint8_t  new_data_flag = 0;
uint8_t  rcv_btn_flag  = 0;
uint8_t  rcv_btn       = 0;
uint8_t  waveform      = 0;
uint8_t  filter        = 0;
uint8_t  audio_on      = 0;
 int16_t prev_z        = 0;
uint16_t vco_ctrl      = 8000;

#if _GLOVE
	char  xmit_data[5] = {0};
#else
	char  spi_miso_buf[MAX_API_FRAME_SIZE];
	char  sns_data[5] = {0};
#endif

/***** INTERRUPTS *****/
#if _UART_ON
ISR(USART_RX_vect)
{
	char rxdata = (char)getByte();
	char rfTX[2] = {rxdata,'\0'};
	
	spi_xmit_api_string(rfTX);
	#if _ECHO
		putByte(rxdata);	// echo in terminal
	#endif
}
#endif

// enable button push interrupts
ISR(PCINT1_vect) {
	if (BTN0_PRESSED)  { btn0_flag = 1; }
	if (BTN1_PRESSED)  { btn1_flag = 1; }
	if (BTN2_PRESSED)  { btn2_flag = 1; }
	if (BTN3_PRESSED)  { btn3_flag = 1; }
	_delay_ms(100);  // debounce delay
}

/****** FUNCTION DECLARATIONS *****/
void config_io(void);

/****** MAIN FUNCTION ******/
int main(void)
{
	config_io();
	
    while (1) 
    {
		/****** CHECK SPI BUS ******/
 		if (SPI_ATTN_N_LOW)
 		{
	 		char* spi_rxdata = api_frame_decode((spi_read()));
	 		
	 		if (strcmp(spi_rxdata, "TX GOOD") != 0)
	 		{
		 		new_data_flag = 1;
				 #if _GLOVE
					
				 #else
		 			switch (spi_rxdata[0])
					{
						//case '0':	strcpy(sns_data,spi_rxdata);	break;
						case '0':
							for(uint8_t i=0; i<5; i++)
							{
								sns_data[i] = spi_rxdata[i];
							}
							break;
						case '1':
							rcv_btn_flag = 1;
							rcv_btn      = spi_rxdata[1];
							break;
						default:		break;
					}
				 #endif
	 		}
 		}
 		
		if (btn0_flag)
		{
			PORTD ^= (1<<LED0);
			btn0_flag = 0;
			#if _GLOVE
			char btn_data[2] = {'1','0'};
			spi_xmit_api_string(btn_data);
			#endif
		}
		
		if (btn1_flag)
		{
			PORTD ^= (1<<LED1);
			btn1_flag = 0;
			btn2_flag = 0;
			#if _GLOVE
				char btn_data[2] = {'1','1'};
				spi_xmit_api_string(btn_data);
			#endif
		}
		
		if (btn2_flag)
		{
			PORTD ^= (1<<LED0);
			btn2_flag = 0;
			#if _GLOVE
				char btn_data[2] = {'1','2'};
				spi_xmit_api_string(btn_data);
			#endif
		}
		
		if (btn3_flag)
		{
			PORTD ^= (1<<LED1);
			btn3_flag = 0;
			#if _GLOVE
				char btn_data[2] = {'1','3'};
				spi_xmit_api_string(btn_data);
			#endif
		}
		
		#if _GLOVE
// 			char* ag_data       = read_gyroacc();
// 			// set type of transmission byte (ASCII 0 = sensor data)
// 			xmit_data[0] = '0';
//  			// place accelerometer and gyroscope data into transmit data buffer
//  			for (uint8_t i = 0; i < 12; i++)
//  			{
//  				xmit_data[i+1] = ag_data[i];
//  			}
//  			// read and store flex sensor
//  			ADC_STRT();
//  			while( ADCSRA & (1<<ADSC) );
//  			xmit_data[14] = ADC>>8;
//  			xmit_data[13] = ADC & 0xFF;

			char* ag_data    = read_acc_z();
			xmit_data[0] = '0';
			xmit_data[1] = ag_data[0];
			xmit_data[2] = ag_data[1];
			ADC_STRT();
			while( ADCSRA & (1<<ADSC) );
			xmit_data[3] = ADC & 0xFF;
			xmit_data[4] = ADC>>8;
 			// transmit sensor data
 			spi_xmit_api_string(xmit_data);
		#else
			if (new_data_flag)
			{
				int16_t a_x      = 0;
				int16_t a_z      = ( (sns_data[ 2]<<8) | sns_data[ 1]);
			   uint16_t adc_data = ( (sns_data[ 4]<<8) | sns_data[ 3]);
// 				 int16_t g_x      = ( (sns_data[ 2]<<8) | sns_data[ 1]);
// 				 int16_t g_y      = ( (sns_data[ 4]<<8) | sns_data[ 3]);
// 				 int16_t g_z      = ( (sns_data[ 6]<<8) | sns_data[ 5]);
// 				 int16_t a_x      = ( (sns_data[ 8]<<8) | sns_data[ 7]);
// 				 int16_t a_y      = ( (sns_data[10]<<8) | sns_data[ 9]);
// 				 int16_t a_z      = ( (sns_data[12]<<8) | sns_data[11]);
// 				uint16_t adc_data = ( (sns_data[14]<<8) | sns_data[13]);
				#if _UART_ON
// 					writeString("GX: ");
// 					writeNum(g_x);
// 					writeString("\t\tGY: ");
// 					writeNum(g_y);
// 					writeString("\t\tGZ: ");
// 					writeNum(g_z);
// 					writeString("\t\tAX: ");
// 					writeNum(a_x);
// 					writeString("\t\tAY: ");
// 					writeNum(a_y);
					writeString("\t\tAZ: ");
					writeNum(a_z);
	 				writeString("\t\tADC: ");
	 				writeNum(int16_t(adc_data));
					writeString("\r\n");
				#endif
				
				if (a_z < 0) { a_z = 0;        }
				else         { a_z = a_z << 0; }
				if (a_x < 0) { a_x = 0;        }
				else         { a_x = a_x << 4; }
				adc_data = adc_data << 2;
				
				if (audio_on)
				{
					if (filter) { i2c_write_two(AD5694_ADDR, (DAC_WR_UPDATE|DAC_VCF), (adc_data>>8), (adc_data & 0xFF)); }
					else        { i2c_write_two(AD5694_ADDR, (DAC_WR_UPDATE|DAC_VCA), (adc_data>>8), (adc_data & 0xFF)); }
					i2c_write_two(AD5694_ADDR, (DAC_WR_UPDATE|DAC_VCO), (a_z>>8), (a_z & 0xFF));
				}
				else
				{
					i2c_write_two(AD5694_ADDR, (DAC_WR_UPDATE|DAC_VCA), 0x00, 0x00);
					i2c_write_two(AD5694_ADDR, (DAC_WR_UPDATE|DAC_VCO), 0x00, 0x00);
					i2c_write_two(AD5694_ADDR, (DAC_WR_UPDATE|DAC_VCF), 0x00, 0x00);
				}
				
				new_data_flag = 0;
			}
			if (rcv_btn_flag)
			{
				switch (rcv_btn)
				{
					case '0':
						audio_on ^= 0x01;
						break;
					case '1': break;
					case '2':
						switch (filter)
						{
							case 0:
								i2c_write_byte_no_addr(PCF8574A_ADDR, (WF_SQR | FLT_DIR) );
								filter ++;
								break;
							case 1: 
								i2c_write_byte_no_addr(PCF8574A_ADDR, (WF_SQR | FLT_HPF) );
								filter = 0;
								break;
							default:  break;
						}
						break;
					case '3':
						switch (waveform)
						{
							case 0:
								i2c_write_byte_no_addr(PCF8574A_ADDR, (WF_SIN | FLT_DIR) );
								waveform ++;
								break;
							case 1:
								i2c_write_byte_no_addr(PCF8574A_ADDR, (WF_SQR | FLT_DIR) );
								waveform = 0;
								break;
							default:  break;
						}
						break;
					default:  break;
				}
				rcv_btn_flag = 0;
			}
		#endif
	
		#if _GLOVE
			_delay_ms(20);
		#else
			_delay_ms(1);
		#endif
    }
	
	return 0;
}


void config_io(void)
{
	// enable all interrupts
	sei();

	// initialize SPI as master
	spi_master_init();
	// configure XBee to SPI mode
	xbee_config_spi();
	// initialize i2c interface
	i2c_master_init();
	// enable LED and button IO and interrupts
	LED_OUT_EN();
	BTN_IN_EN();
	BTN_INT_EN();
	BTN_INTMSK();
	
	#if _UART_ON
		// enable uart interrupt
		RX_INTEN();
		// initialize UART interface
		initUART();
	#endif

	#if _GLOVE
		// configure 6DoF
		LSM6DS3_init();
		// enable ADC
		ADC_IN1_SEL();
		ADC_EN();
	#else
		// set LOAD DAC signal
		LDAC_OUT_EN();
		LDAC_N_ON();
		i2c_write_byte_no_addr(PCF8574A_ADDR, (WF_SIN | FLT_DIR) );
		i2c_write_two(AD5694_ADDR, DAC_PWR,                 0x00, 0x00);
		i2c_write_two(AD5694_ADDR, (DAC_WR_UPDATE|DAC_VCO), 0x20, 0x80);
		i2c_write_two(AD5694_ADDR, (DAC_WR_UPDATE|DAC_VCF), 0x08, 0x80);
		i2c_write_two(AD5694_ADDR, (DAC_WR_UPDATE|DAC_VCA), 0x00, 0x80);
	#endif
}

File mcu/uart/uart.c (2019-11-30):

/*
 * uart.c
 *
 * Asynchronous UART example tested on ATMega328P (16 MHz)
 *
 * Toolchain: avr-gcc (4.3.3)
 * Editor: Eclipse Kepler (4)
 * Usage:
 * 		Perform all settings in uart.h and enable by calling initUART(void)
 * 		Compile:
 * 				make all
 *
 * Functions:
 * 		- First call initUART() to set up Baud rate and frame format
 *		- initUART() calls macros TX_START() and RX_START() automatically
 *		- To enable interrupts on reception, call RX_INTEN() macros
 *		- Call functions getByte() and putByte(char) for character I/O
 *		- Call functions writeString(char*) and readString() for string I/O
 *
 *  Created on: 21-Jan-2014
 *      Author: Shrikant Giridhar
 */

#include "uart.h"

// Debug Mode; comment out on Release
#define _DEBUG			0


/*! \brief Configures baud rate (refer datasheet) */
void initUART(void)
{
	// Not necessary; initialize anyway
	DDRD |= _BV(PD1);
	DDRD &= ~_BV(PD0);

	// Set baud rate; lower byte and top nibble
	UBRR0H = ((_UBRR) & 0xF00);
	UBRR0L = (uint8_t) ((_UBRR) & 0xFF);

	TX_START();
	RX_START();

	// Set frame format = 8-N-1
	UCSR0C = (_DATA << UCSZ00);

}

/*! \brief Returns a byte from the serial buffer
 * 	Use this function if the RX interrupt is not enabled.
 * 	Returns 0 on empty buffer
 */
uint8_t getByte(void)
{
	// Check to see if something was received
	while (!(UCSR0A & _BV(RXC0)));
	return (uint8_t) UDR0;
}


/*! \brief Transmits a byte
 * 	Use this function if the TX interrupt is not enabled.
 * 	Blocks the serial port while TX completes
 */
void putByte(unsigned char data)
{
	// Stay here until data buffer is empty
	while (!(UCSR0A & _BV(UDRE0)));
	UDR0 = (unsigned char) data;

}

/*! \brief Writes an ASCII string to the TX buffer */
void writeString(char *str)
{
	while (*str != '\0')
	{
		putByte(*str);
		++str;
	}
}

/* convert an nteger to ascii characters and write to TX buffer */
void writeNum(int16_t num)
{
	uint8_t  zero_flag = 0;
	int16_t val       = 0;
	
	if (num < 0)
	{
		putByte('-');
		num *= -1;
	}
	
	for(int16_t comp=10000; comp > 0; comp/=10)
	{
		val  = num/comp;
		if ( (val != 0) || (zero_flag == 1) )
		{
			zero_flag = 1;
			putByte('0'+ (val&0xFF) );
			num -= val*comp;
		}
	}
}

const char* readString(void)
{
	char rxstr[RX_BUFF];
	char* temp;
	temp = rxstr;

	while((*temp = getByte()) != '\n')
	{
		++temp;
	}

	return rxstr;
}

#if _DEBUG

	int main(void)
	{
		initUART();
		while(1)
		{
			writeString(readString());
			putByte('\r');
			putByte('\n');
		}
		return 0;
	}

#endif

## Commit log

2019-10-04 added SPI reading and decoding from xbee
2019-10-18 first cut of wiproc schematic
    [batt_chrg.sch, mcu_atmega328p.sch, usb_uart.sch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]
2019-10-28 routed wiproc, created synth pcb
    [analog_cond.sch, batt_chrg.sch, mcu_atmega328p.sch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]
2019-11-04 analog synth updates
    [audio.sch, dig_ctrl.sch, mux.sch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]
2019-11-05 inital synth schematic
    [ana_scale.sch, ana_scale_vco.sch, dig_ctrl.sch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]
2019-11-28 final pcb designs and initial i2c
    [ana_scale.sch, dig_ctrl.sch, mux.sch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]
2019-11-28 added i2c device libraries
2019-11-30 implemented 2 wiproc design with one streaming to other and printing to terminal
    [ana_scale.sch, vco.sch]
2019-12-08 only accelerometer Z-axis used
